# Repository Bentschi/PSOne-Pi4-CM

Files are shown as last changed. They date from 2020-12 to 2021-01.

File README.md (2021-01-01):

## Introduction
The goal of this project is to create open source hardware and software that replaces parts of a PSOne console mainly with a Raspbery PI 4 Compute Module, while remaining the beauty of the console and most of the functionality.
That means you would be able to use your playstation dualshock controllers, the memory card slots, and if i can get it to work the cd drive aswell.

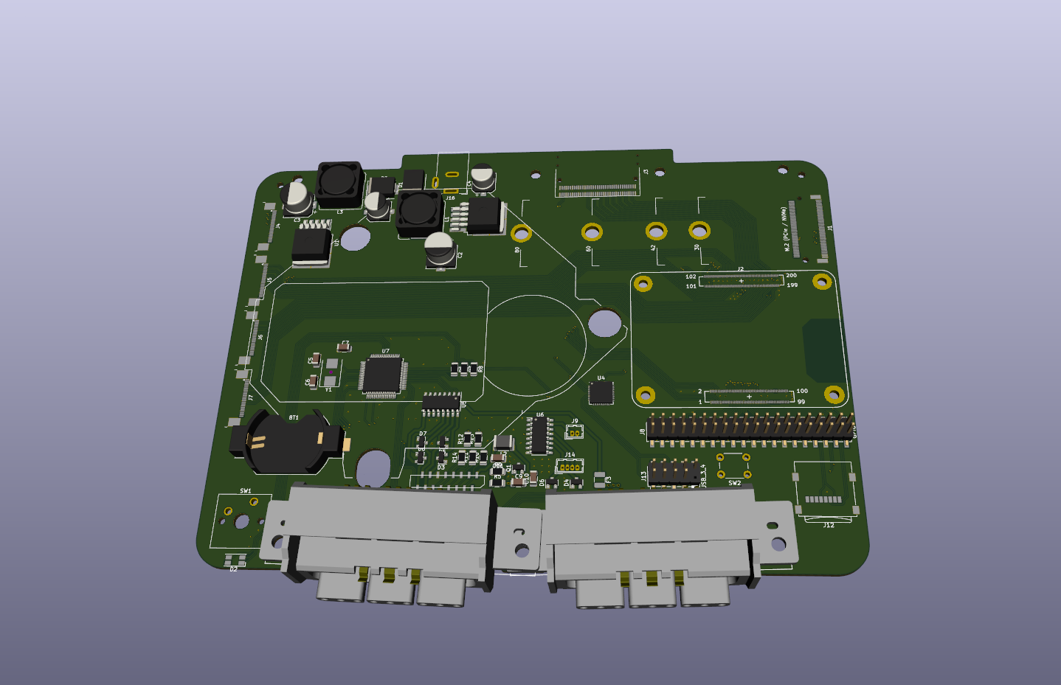
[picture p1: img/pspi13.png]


## Raspberry Pi 4 Compute Module - the heart
As mentioned it will be mainly powered by a Raspberry PI 4 Compute Module, and i will try to break out as much IO as reasonably possible.
Sadly in a PSOne with a CD drive there is not much room to work with, and I decided for a non-destructive method of routing out the ports.
I want to use the connector U10-A074-361T from Amphenol (also known as Slim SAS, and used mostly in servers).
The connector is not really cheap and a little wider than the AV multi out.
But that is the price to pay to not destroy the case of the console, and if the connector is inset in the existing hole it will fit.
With that connector I will route dual HDMI, the gigabit network interface and USB 2.0 out of the back.
As a power port I will use a USB type C receptacle.
A cable that connects to that connector could look something like the following picture.

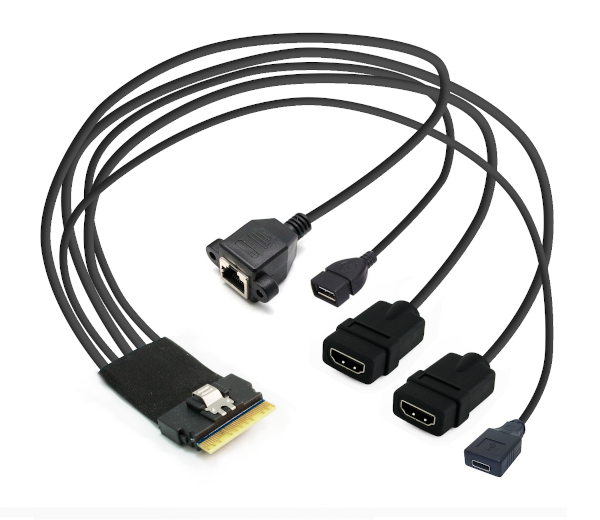
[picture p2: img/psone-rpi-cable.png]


Alternatively a hub could be designed with said ports and maybe a few extras like usb hub and sound.

I will also add the barrel plug you find on a PSOne.
To save some cost and precious board space the Dual Shock function will most certainly only be enabled by using this barrel plug.
The original PSOne power supply (7.5V / 2.2A) seems to be enough to power this entire system (estimated-power-consumption.ods), however when using a M.2 SSD I would suggest to use a better power supply like the one for the Playstation 2 slim (8.5V / 5.6A).

The PCIe i want to use for a M.2 card interface. and i would love to split the pcie lane for USB 3.0 aswell, but then again i want to stay in a reasonable price range for the parts.
The M.2 slot will be able to hold up to 22x60mm cards, and for 22x80mm cards there would be about 7mm vertical clearance, since the only place where a M.2 slot would make sense interferes a little bit with the cd drive.
Sadly I needed more room for the internal power supply, so I had to remove the footprint (mounting hole) for 22x110mm cards.

I haven't managed to find a good place for a SD card holder, but i will route out the traces at least and put a footprint somewhere internally.
I will route out the DSI and CSI connectors aswell, even if i don't really see a use inside a console for them.

There will be an internal 4 port USB 2.0 hub from the PIs USB 2.0 interface.
One of these 4 USB lines will be routed through the Slim SAS connector.
2 of these USB 2.0 lines will be broken out to an internal 9-Pin USB Header, like you find on motherboards.
And the last USB 2.0 will be used to connect to a STM32F103 chip, that will interface the PSOne peripherals.

## STM32F103 - the PSOne interface
The intended use of the STM32F103 chip is to read from and write to the PSOne controller ports and memory card slots, and hopefully if i can get it to work the cd drive aswell.

The STM32F103 chip will communicate with the Raspberry PI Compute Module via USB 2.0 and will introduce itself as a compound device.
That means that only one USB line is required, and the STM32F103 will be recognized as multiple devices which would be 2x game controllers, 2x mass storage devices (the memory card slots), a cd drive, and probably a device that controls the PWMs for the power LED (RGB of course) and fan in the console.

I want to use a USB type C receptacle to power the console, and i have the idea that if the console is turned off or the Compute Module is not populated, and the console is plugged into a USB Host device (like a Computer), that the USB from the STM32F103 shall be passed through this USB type C connector, so that it is possible to use the PSOne peripherals on other devices aswell.

I am aware that CD drives are obsolete by todays standards, and that it is not gonna be that easy to interface the cd assembly, since there is no documentation about it or a standard like IDE or SATA used.
But for completeness i would want to have it working. And if i get it working it would be pretty simple to make it read actual Playstation CDs since the copy protection is not too complicated if you have full control over the entire CD assembly anyway.

## Cooling the Compute Module
Realisticly a flat fan like in laptops should probably be used and a shroud should be designed, that the air is taken from above the M.2 slot and pushed over the compute module, and with the shroud then directed to the bottom right vent holes on the console.
A connector for a fan (5V / 1A max), PWM controlled by the STM32 will be available, sharing one of the ULN2003 chips that are mainly used for the CD drive.

## Current status
I am currently working on the design and schematic for the board in KiCad.
I want to get as much done as possible until i order a PCB from that to test everything.

I want to mention that I have repaired a lot of older consoles in the past and I have very good knowledge of how these devices actually work.
And with all that knowledge, together with my very good programming skills, and my passion about old consoles and interrest in electronics, i think i have everything i need to get this project working.
But i have to say, even if i am aware of most of the design rules and guidelines, i have never designed a PCB before that i actually ordered to manufacture.
So this would be my very first.

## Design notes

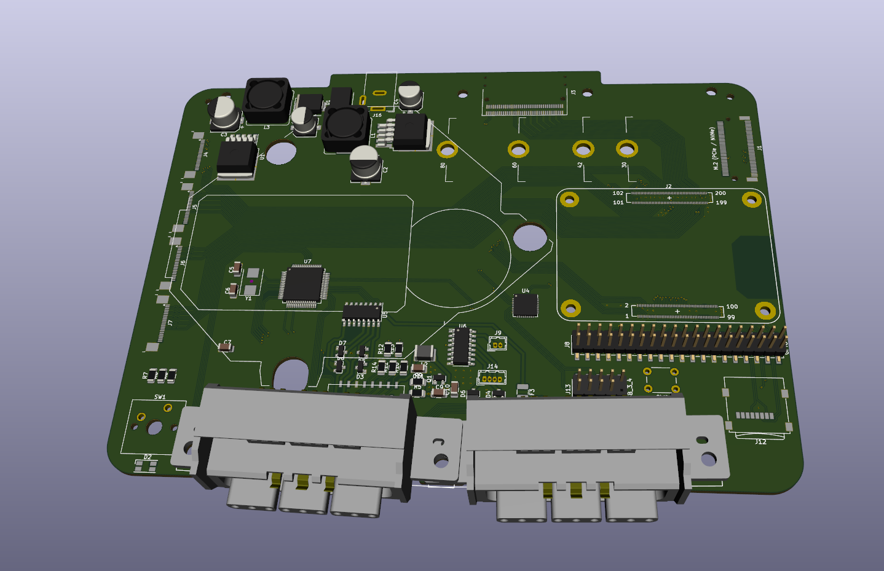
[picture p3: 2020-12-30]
img/pspi12.png

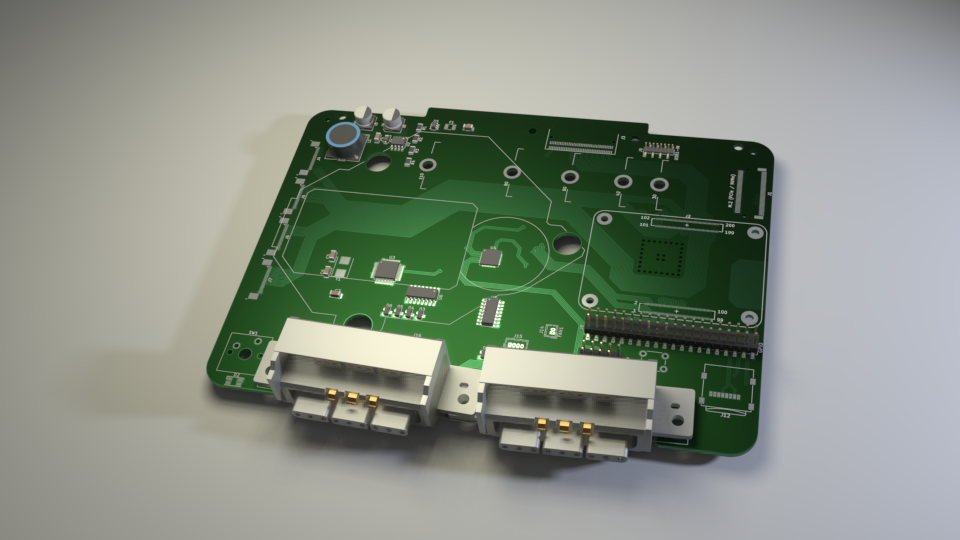
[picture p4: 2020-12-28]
img/pspi11.png

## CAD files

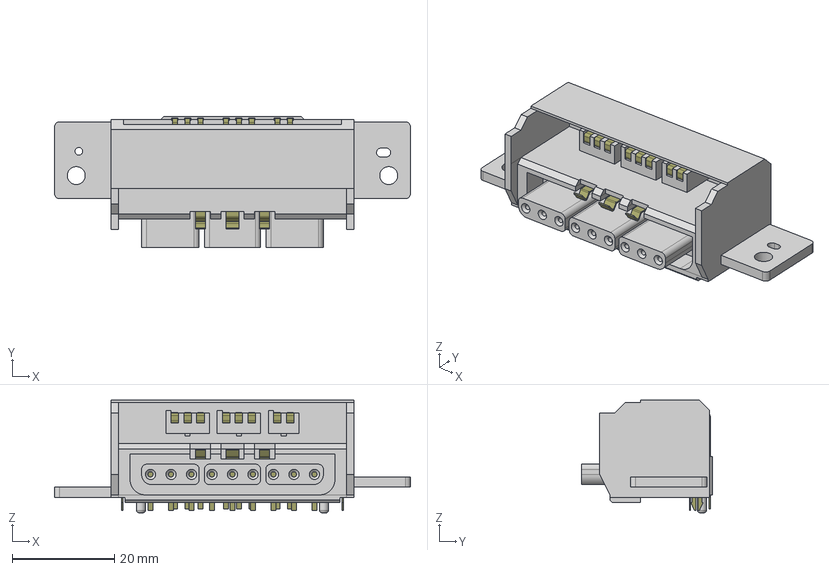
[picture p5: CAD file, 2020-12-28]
freecad/psone-controller-port.step
69.5 x 25.5 x 22.0 mm

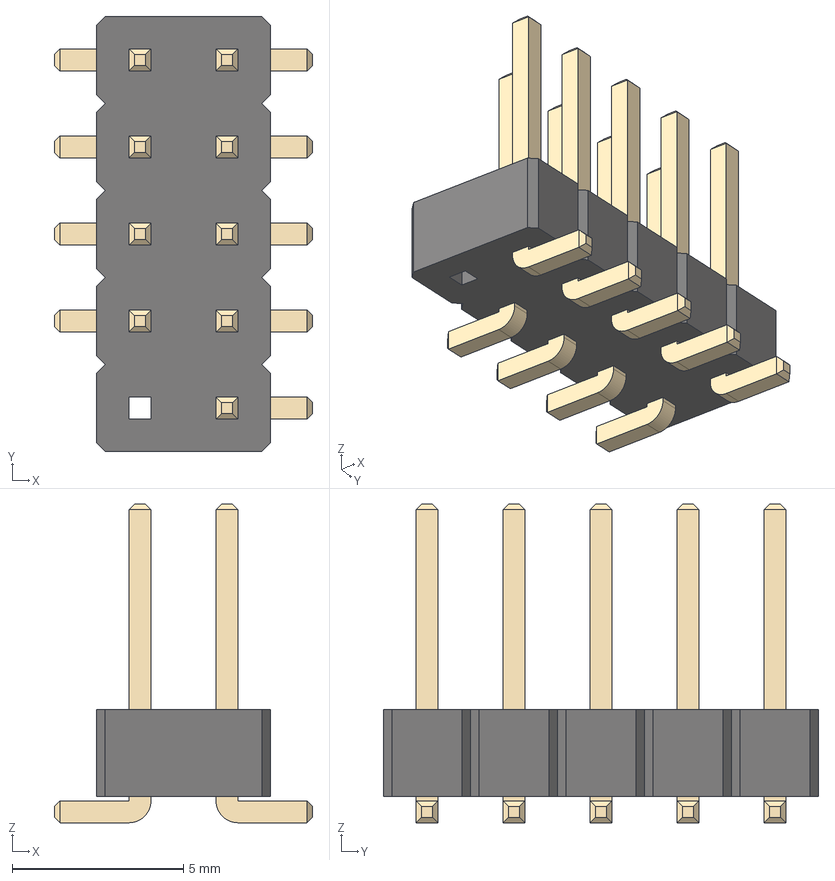
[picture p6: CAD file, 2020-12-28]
freecad/PinHeader_2xUSB2_P2.54mm_Vertical_SMD.step
7.54 x 12.7 x 9.30 mm

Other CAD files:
freecad/psone-controller-port3.FCStd
freecad/PinHeader_2xUSB2_P2.54mm_Vertical_SMD.FCStd

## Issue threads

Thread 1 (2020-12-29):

Need advice for the power supply

Bentschi, 2020-12-29:
Hello,
So here is the scenario:
I want for power inputs a barrel plug with something around the +7.5V like the original PSOne used and alternatively i want to power everything with USB C +5V.

I need obviously +5V for the compute module, HDMI, USB, GPIO and the CD drive (motors)
I need +3.3V for the STM32, the M.2 card interface, the internal USB hub, GPIO, PSOne peripherals and the CD drive (focus and tracking coils and logic)
And I need +7.5V for the rumble motors in Playstation dual shock controllers.

I could consider to take the power for the rumble motors straight from the barrel plug or alternatively +5V and then its just not that powerful.
But i am thinking about taking the voltage from either USB C +5V or from the barrel plug, and convert that with a buck-boost converter to +7.5V.
And use a buck convertor for +5V from that +7.5V.
For +3.3V the 600mA the Compute Module provides would probably be enough, but from what i gather from the datasheet (https://datasheets.raspberrypi.org/cm4/cm4-datasheet.pdf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) the +3.3V output will not be available when the compute module is in low power state.
So i will have to make my own +3.3V circuit for the STM32 that should power down and wake the compute module with the consoles power button.
Therefore I'm thinking about something like a circuit using AMS1117.

Here is what I'm thinking about powering up and down the console:
I want to let the the STM32 pull GLOBAL_EN on the compute module low and sleep if the console is not powered up.
Once the power button is pressed the STM32 should wake up (interrupt) and use RUN_PG as input to know the power state of the compute module.
The compute module should then connect to the STM32 via USB once powered up.
If the power button is pressed when everything is powered up, the STM32 will send a shutdown signal to the compute module (as USB keyboard maybe?) and wait until RUN_PG goes low.
Once RUN_PG goes low, the STM32 should also pull GLOBAL_EN low to prevent powering up the compute module again.
After that the STM32 should go back to sleep.

Is this the right way to do it? Or can I improve something about this?

Bentschi, 2021-01-01:
I did some more research and decided to go with +5V and +3.3V step down converters.
And enable the Dual Shock rumble only with the barrel plug (7.5 - 9V).
Putting all estimated power requirements together in a spread sheet, helped me understanding how the internal power supply should be designed.
In my current design the parts are chosen to be efficient and withstand way more than there should be required, so there is room for modifications.
I still need to design power switches that allow to use a +5V input over the USB type C, and some switches like for M.2 to shut them off when they are not needed, but i think i can get that done without help.

Closed 2021-01-01.

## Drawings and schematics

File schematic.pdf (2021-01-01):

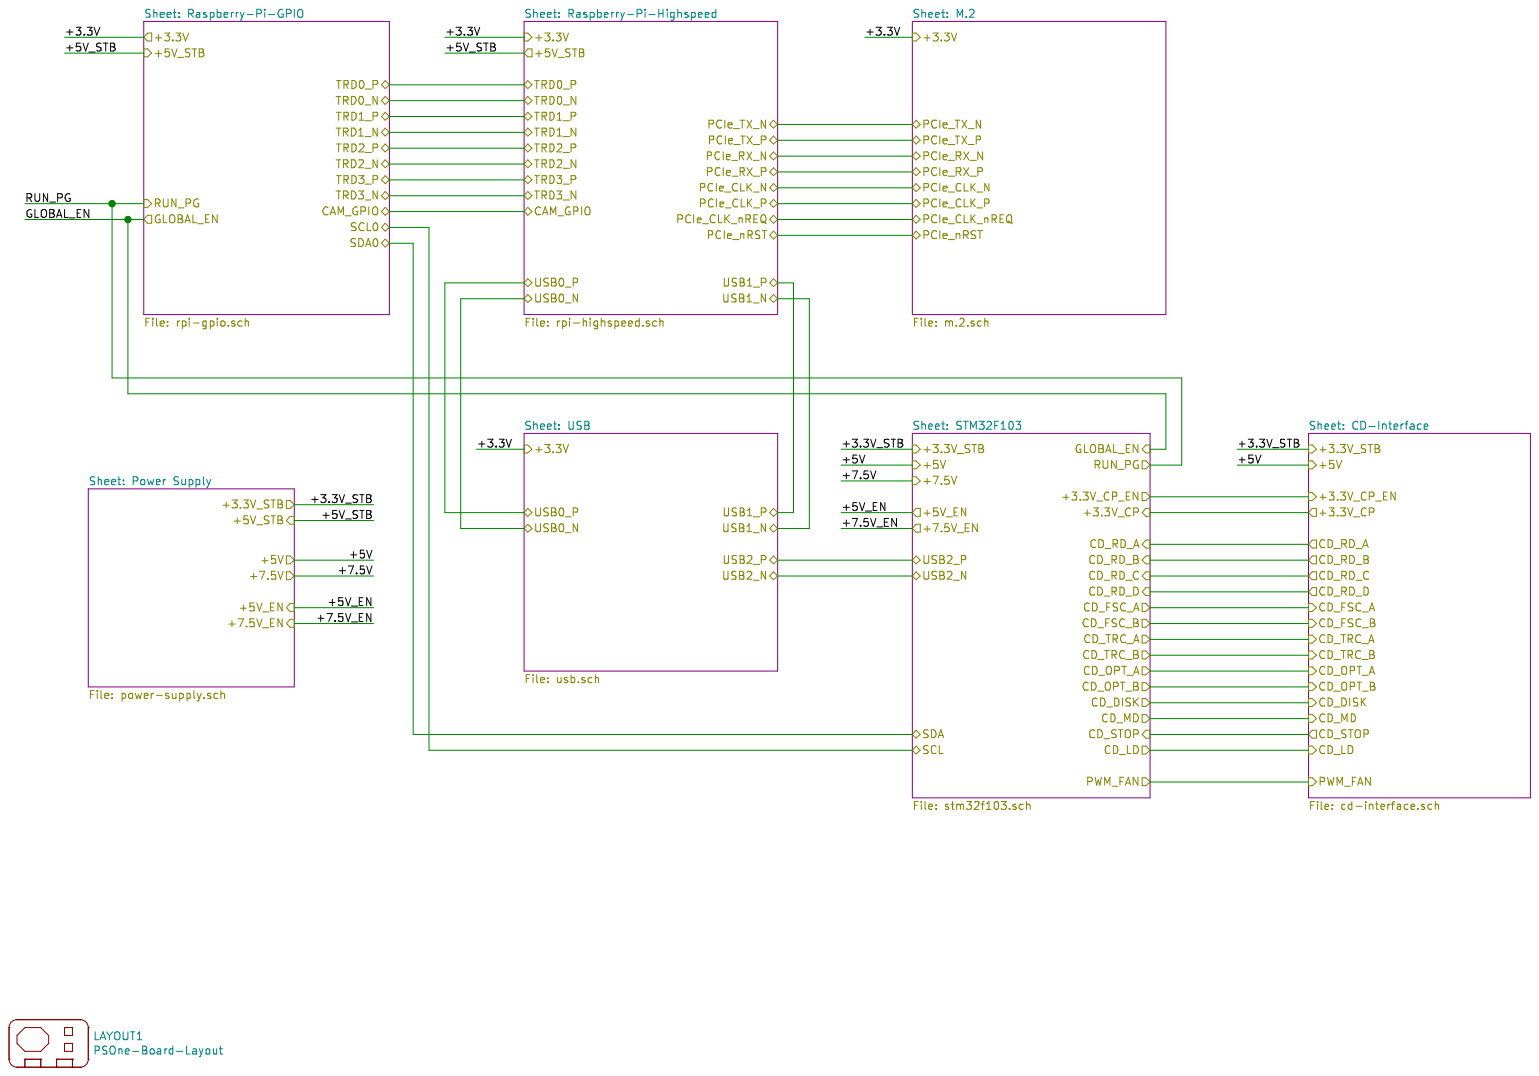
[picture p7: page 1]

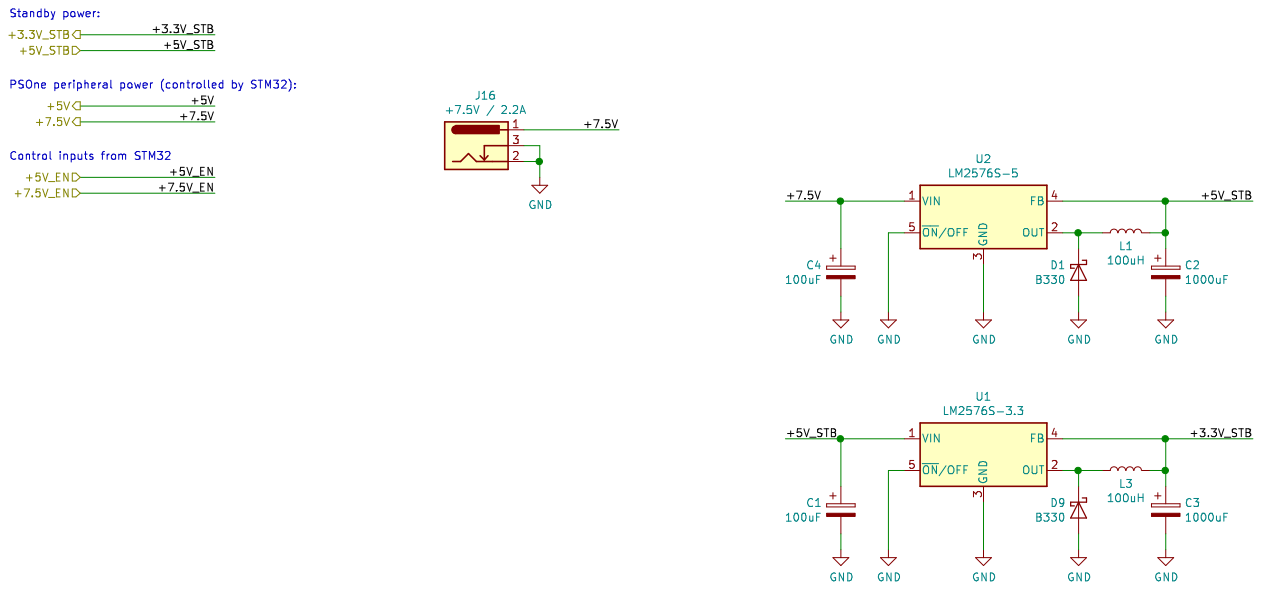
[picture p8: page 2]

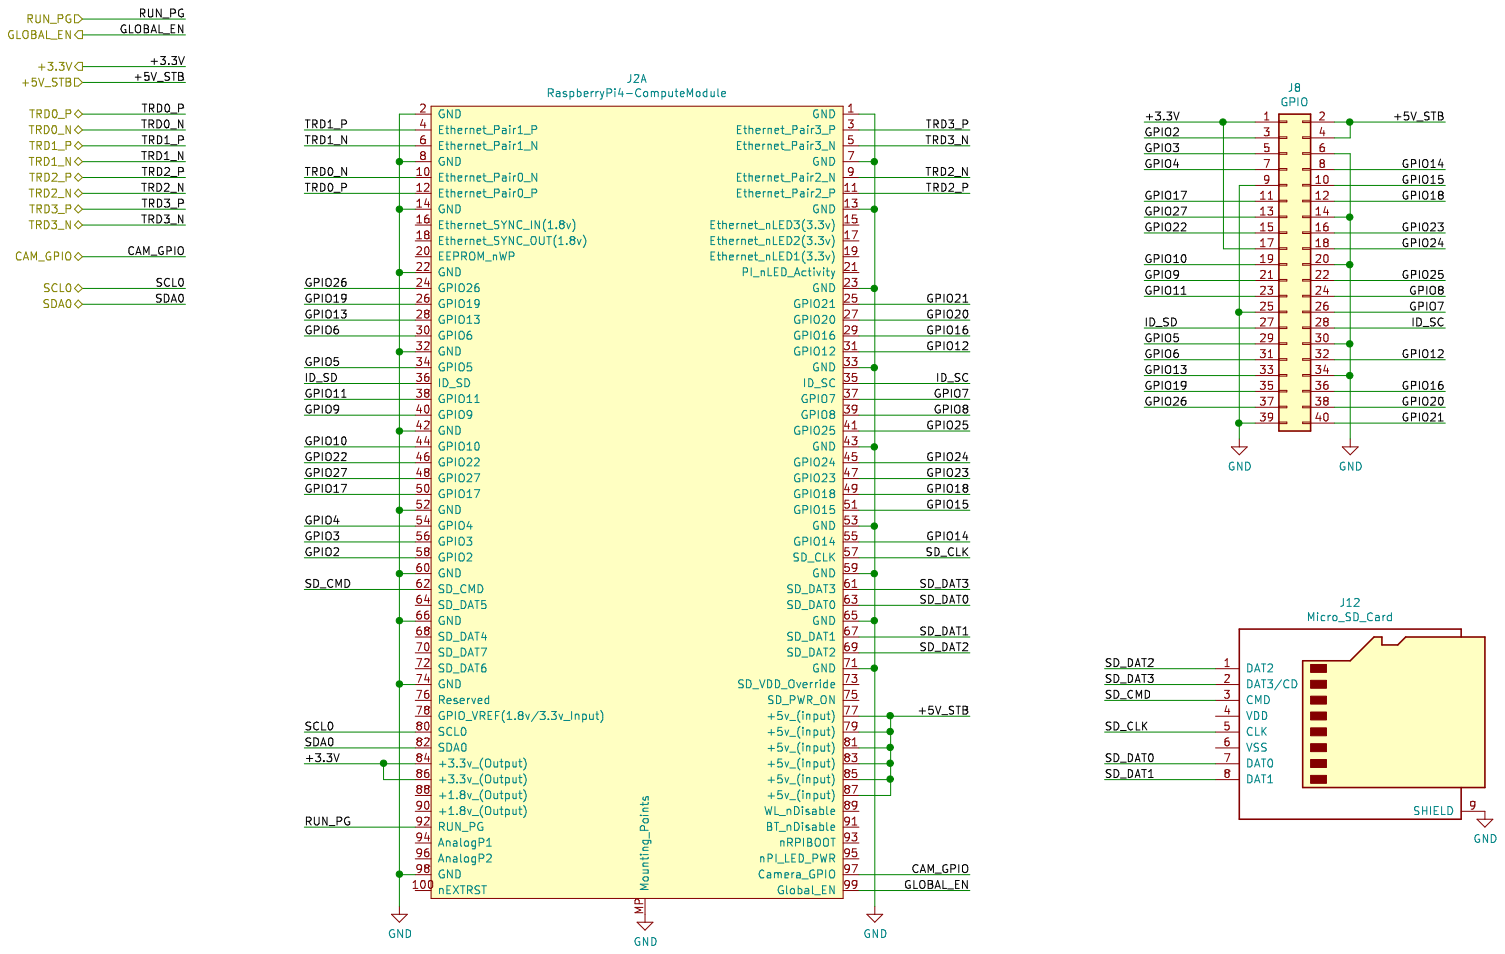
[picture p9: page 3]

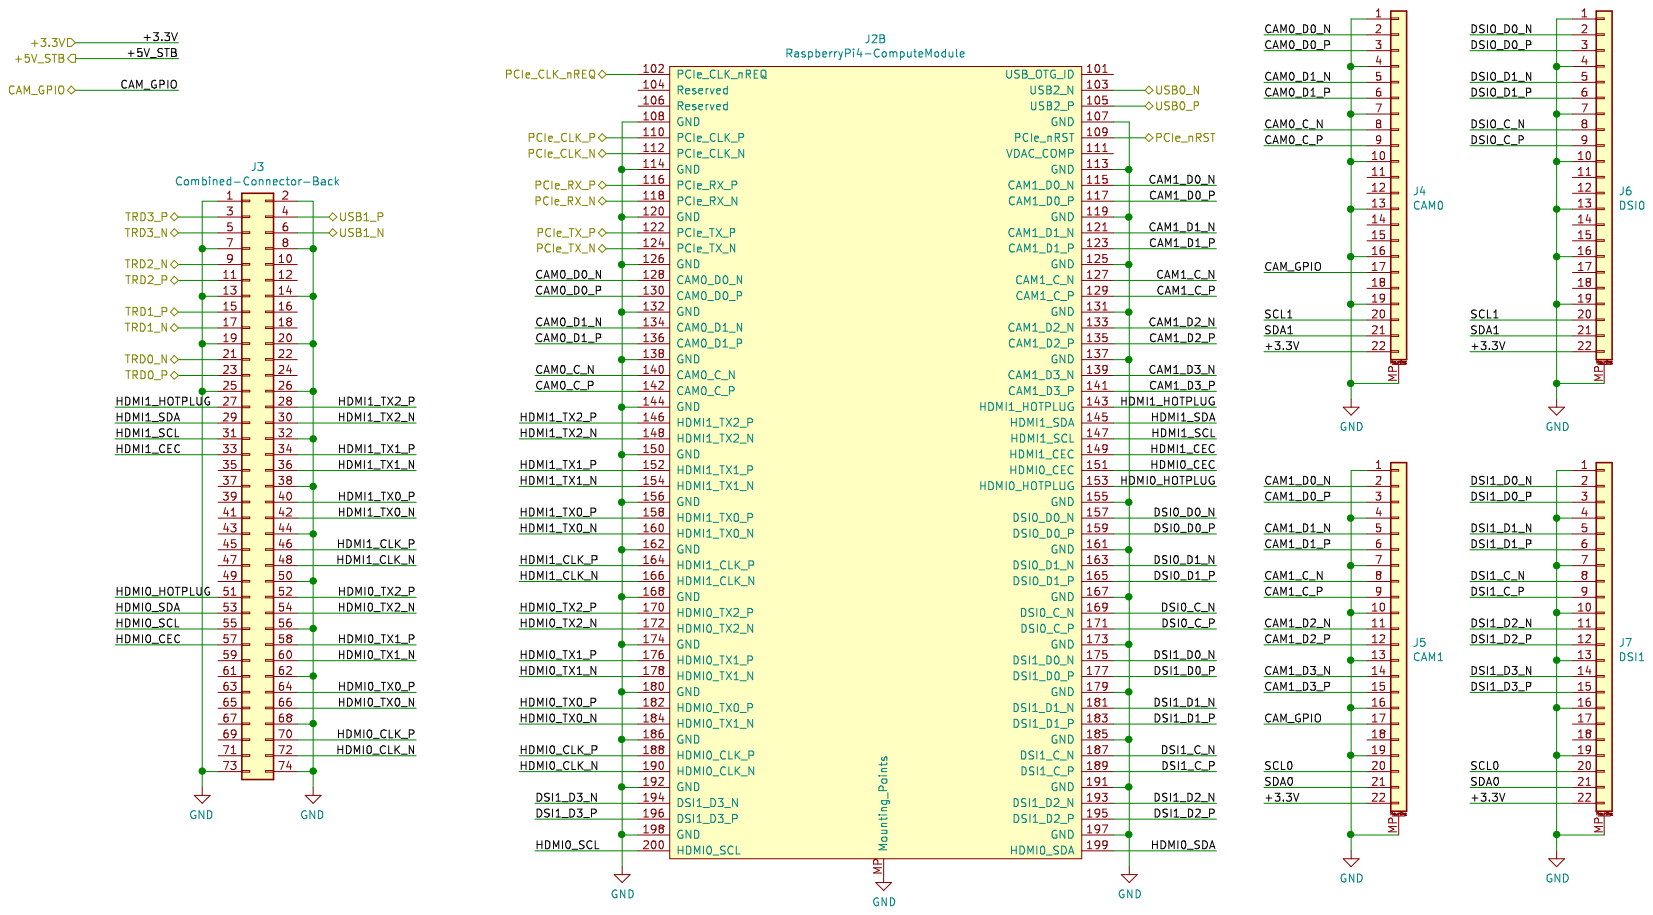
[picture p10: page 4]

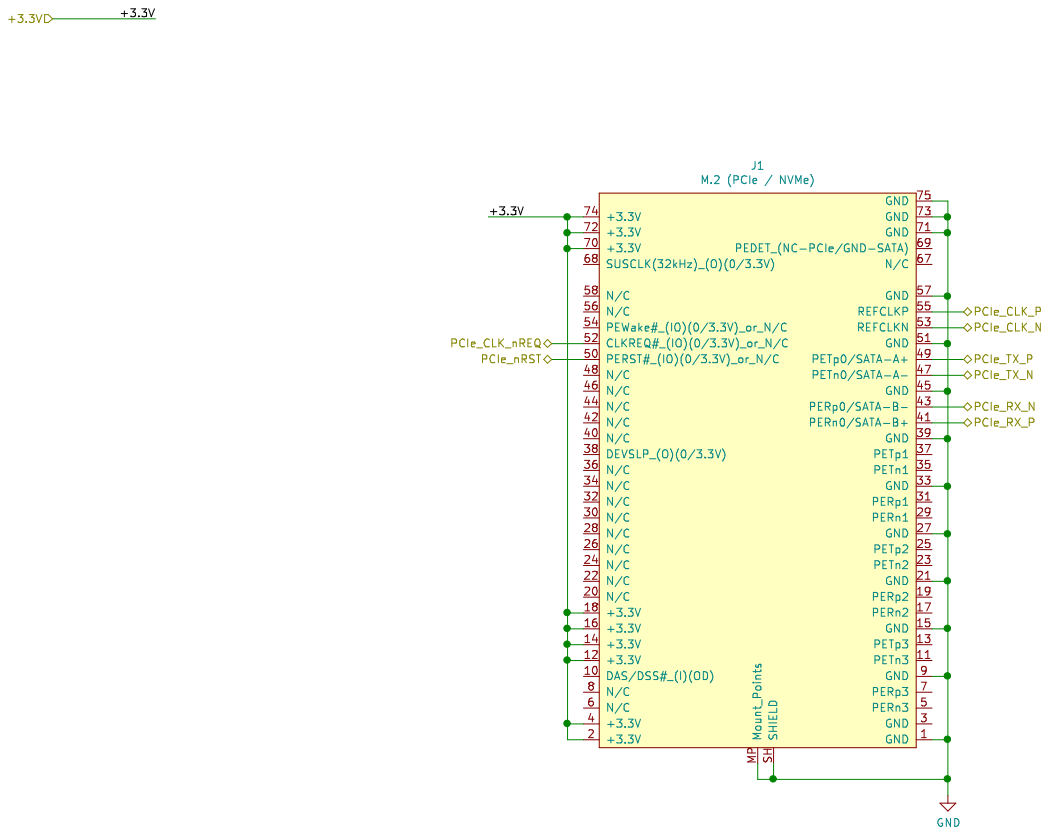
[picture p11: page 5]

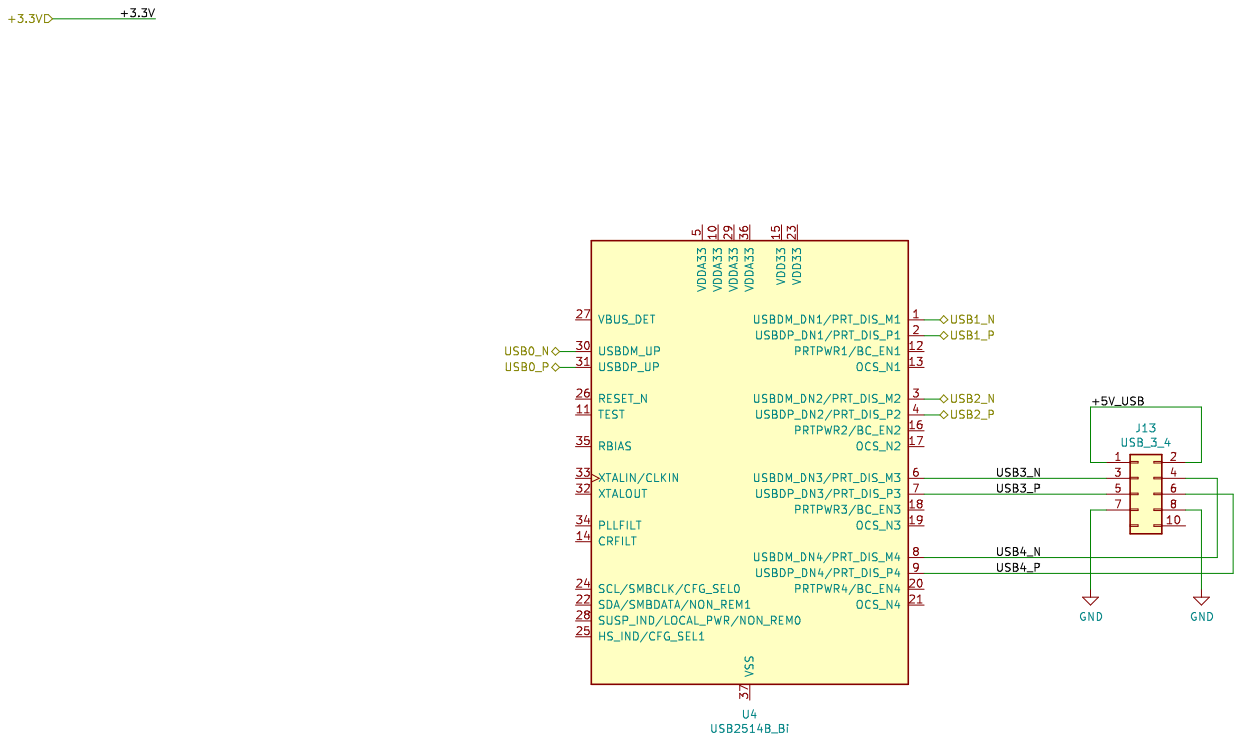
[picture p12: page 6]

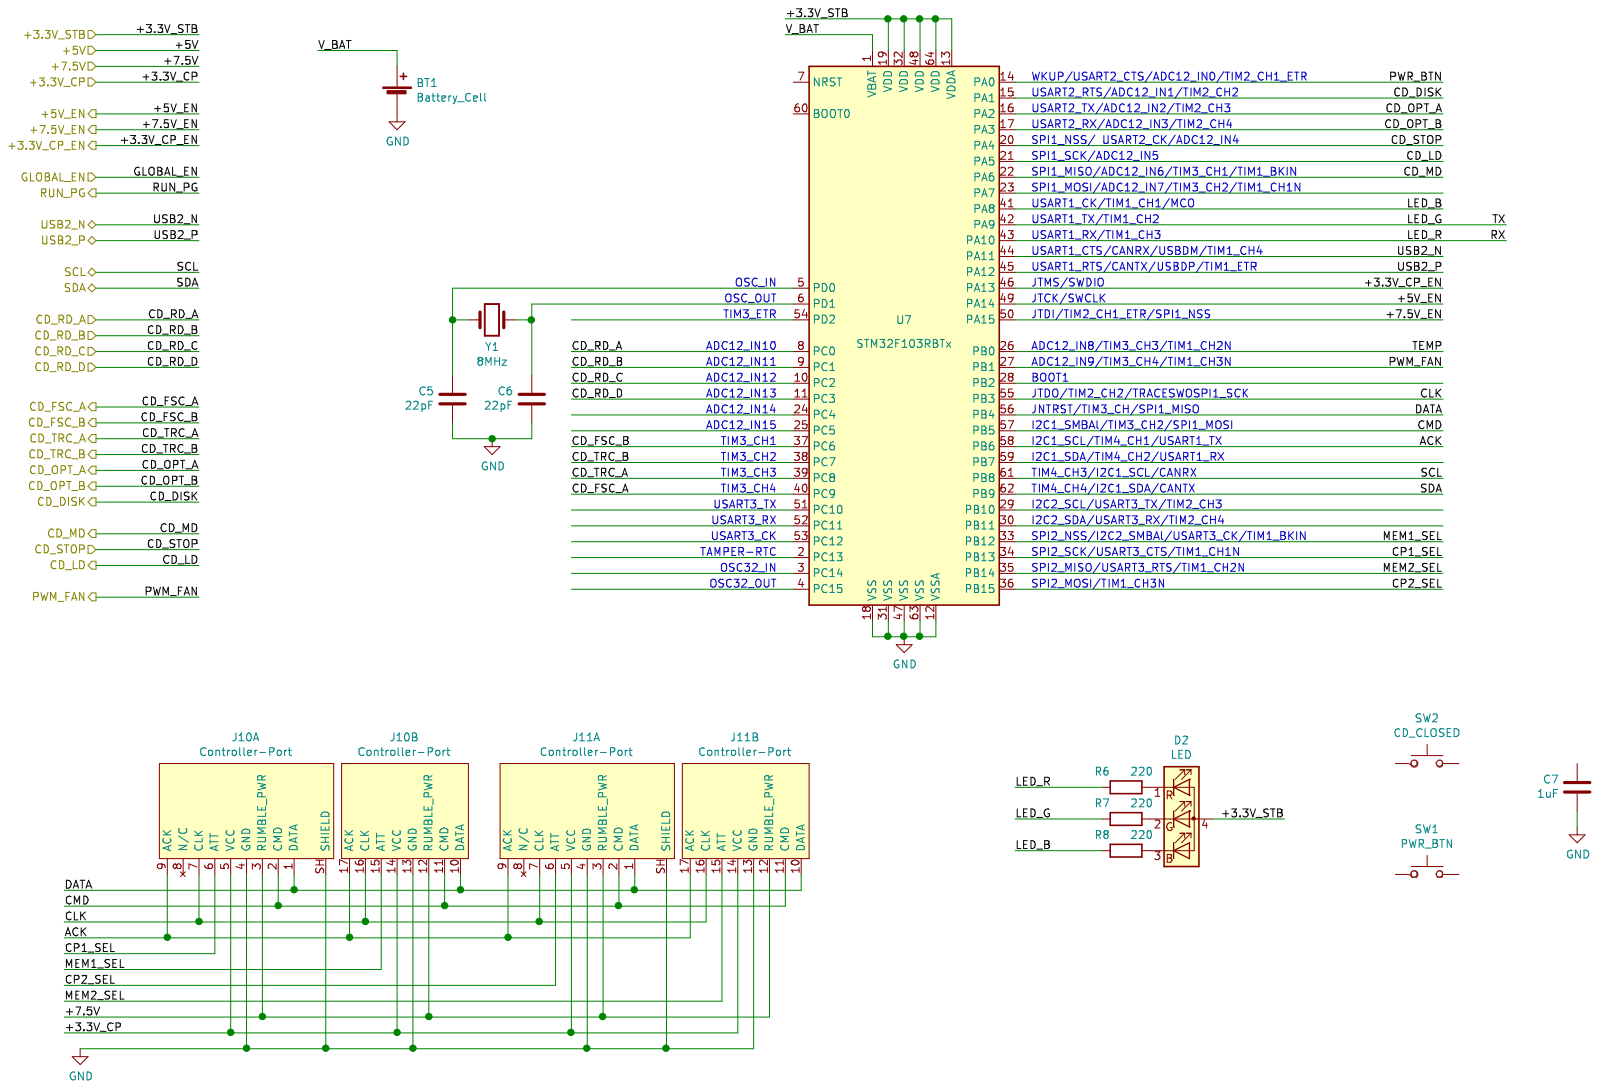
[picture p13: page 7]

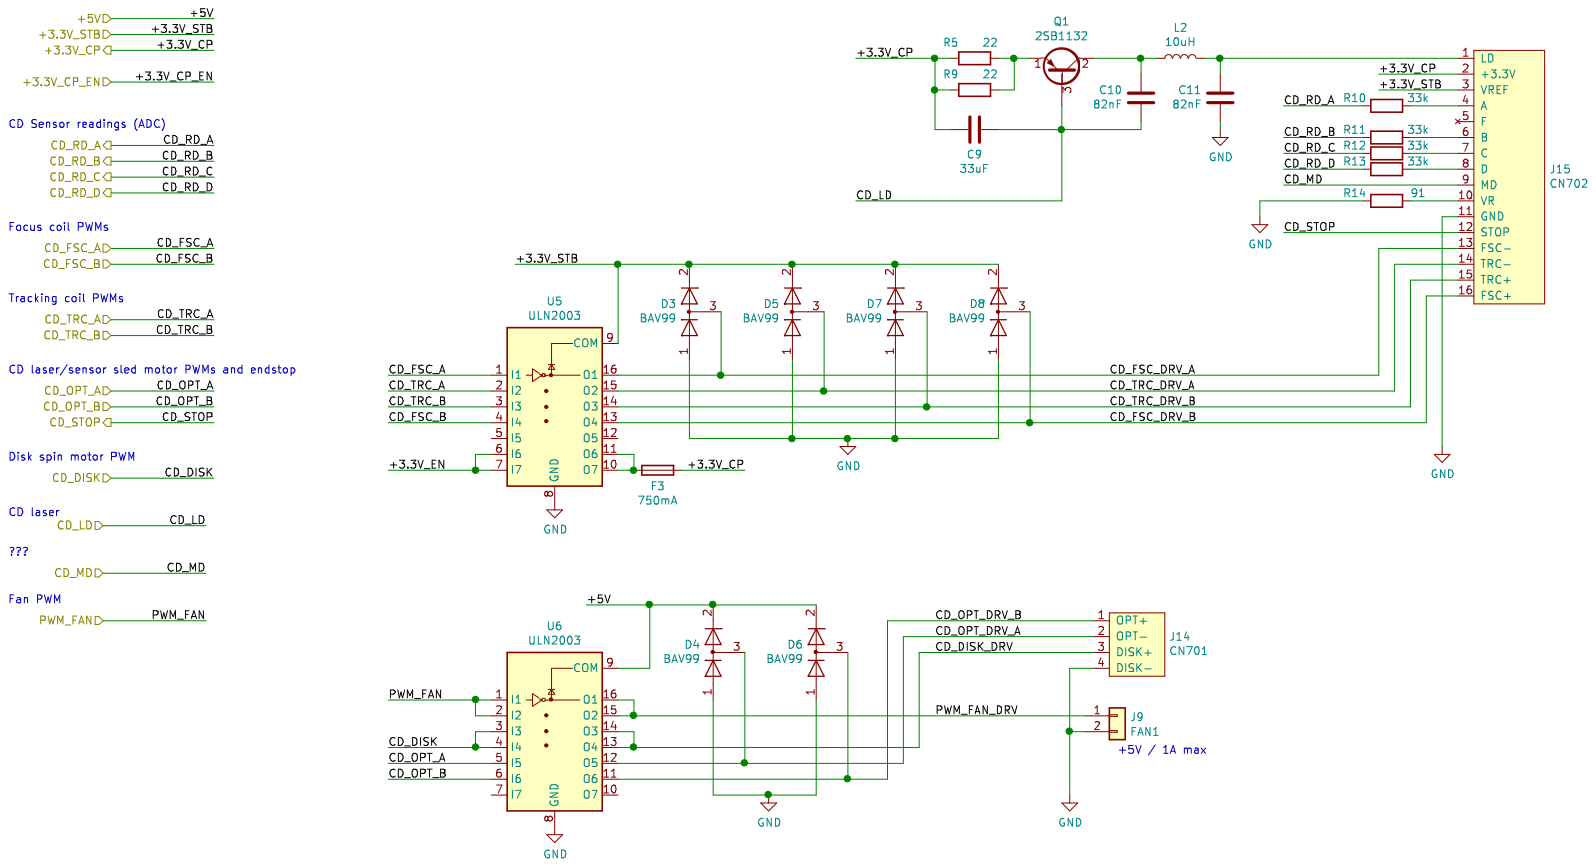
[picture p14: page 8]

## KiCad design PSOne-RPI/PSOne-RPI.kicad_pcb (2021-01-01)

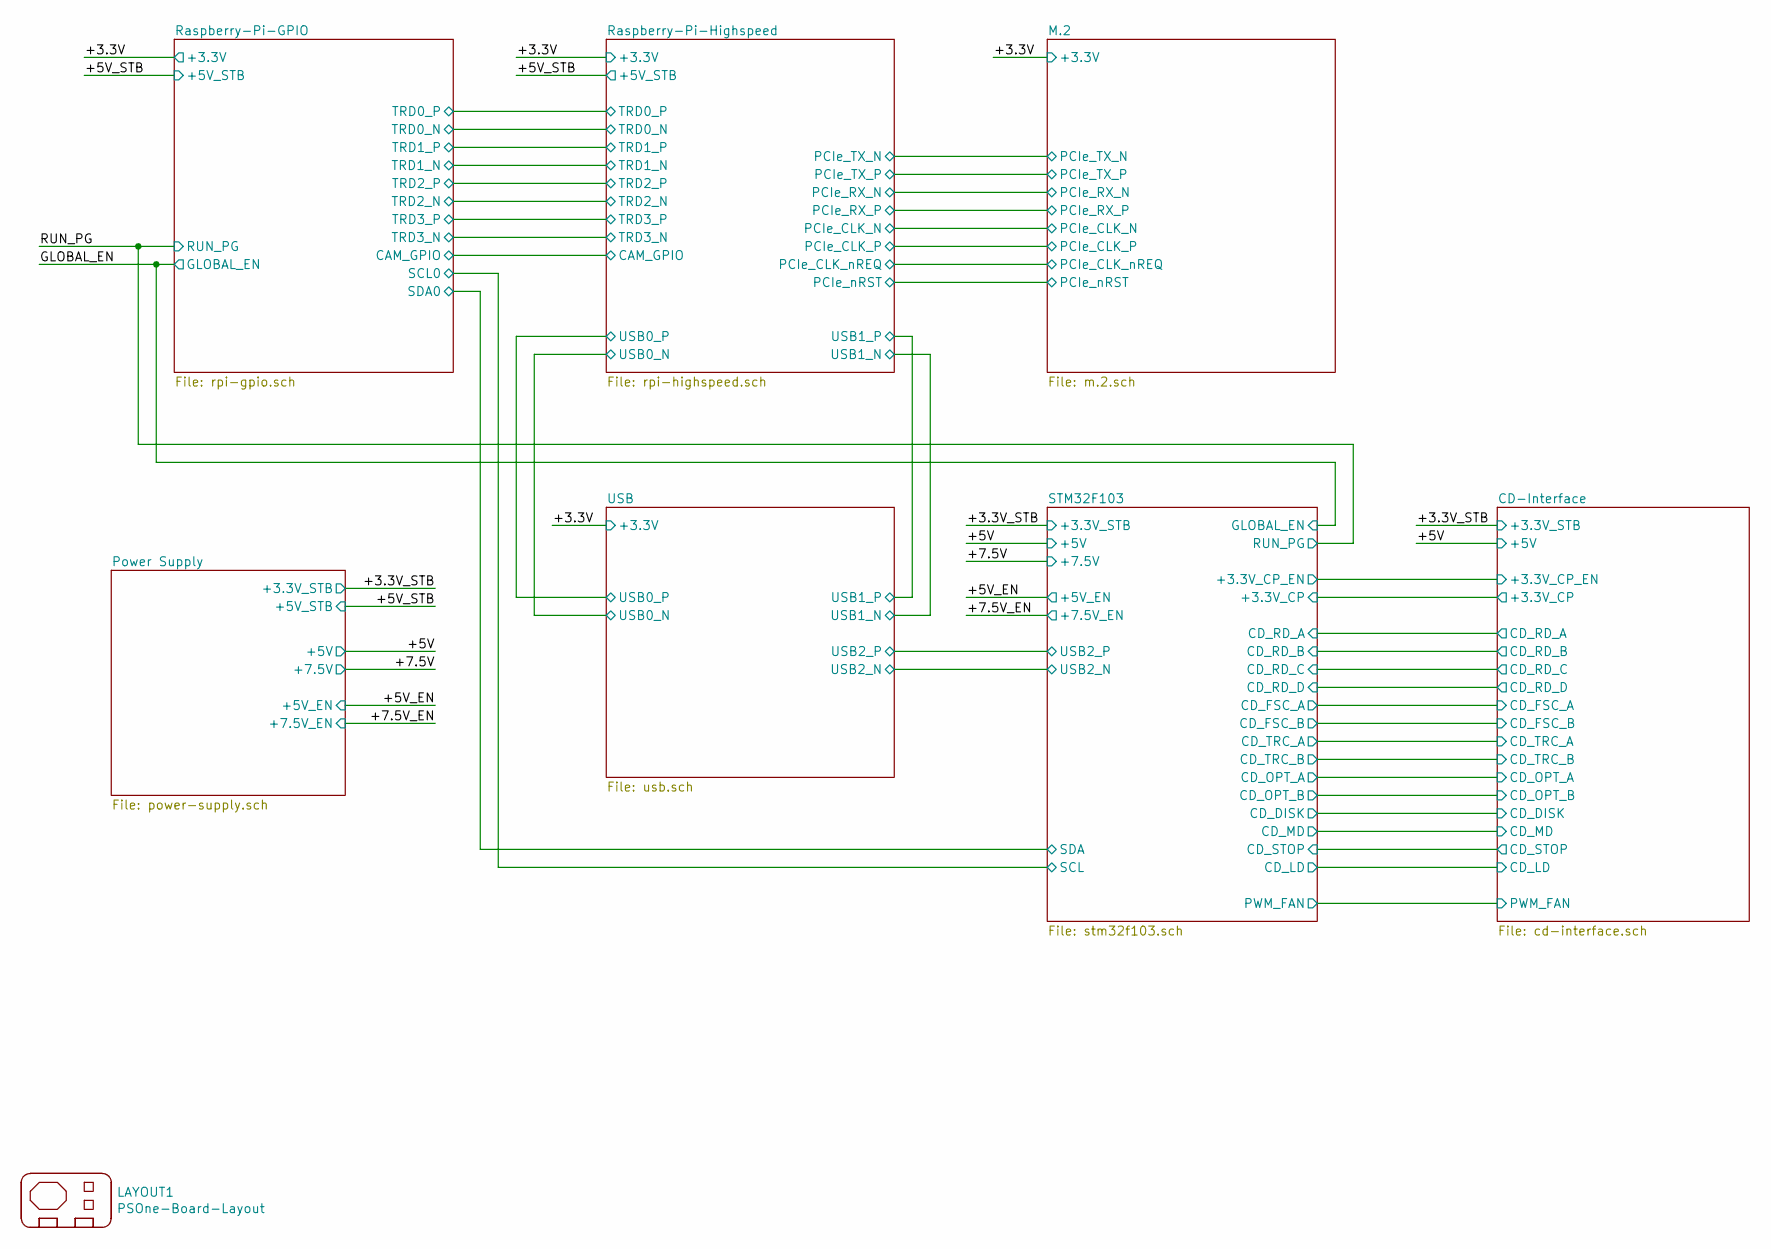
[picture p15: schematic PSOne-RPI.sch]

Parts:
LAYOUT1: PSOne-Board-Layout; PSOne-Layout

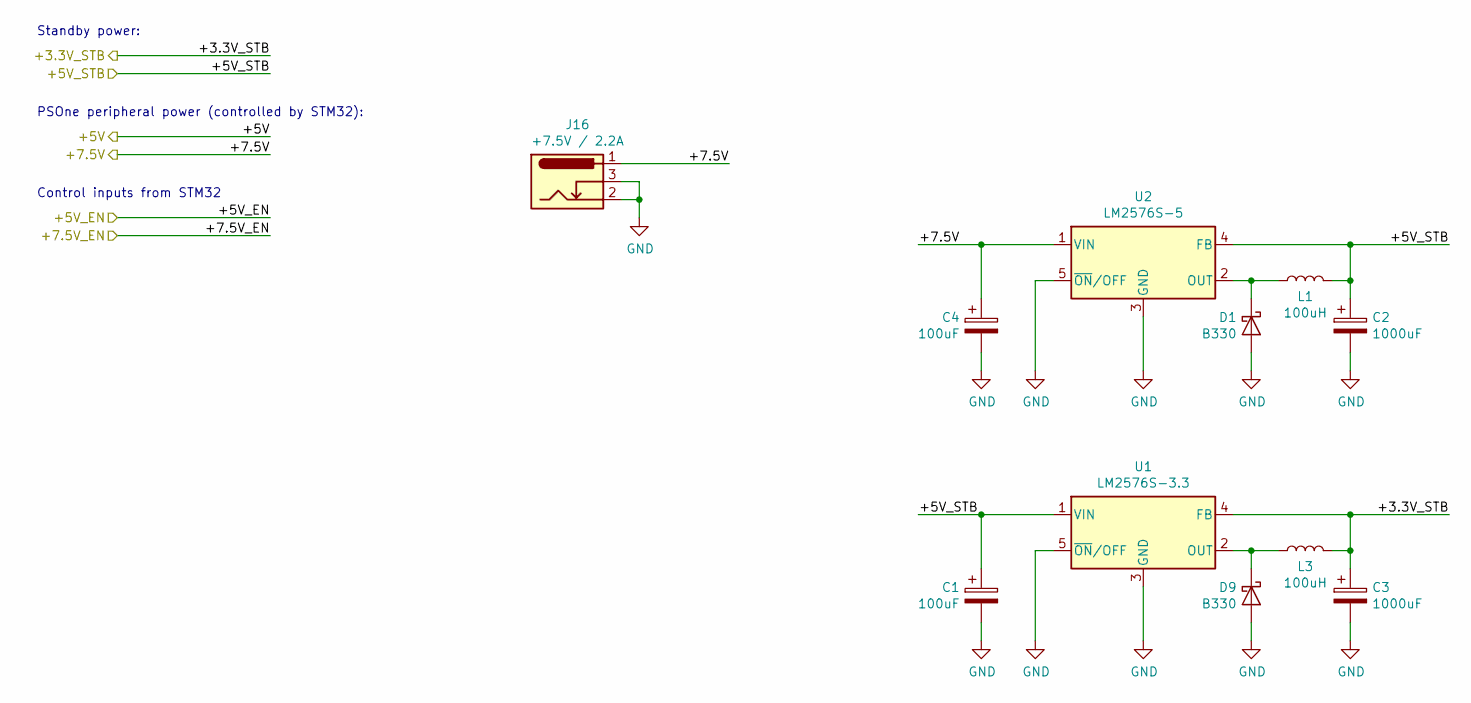
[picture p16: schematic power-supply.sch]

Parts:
C1, C4: 100uF; CP_Elec_6.3x5.8
C2, C3: 1000uF; CP_Elec_8x6.5
D1, D9: B330; D_SMC
J16: +7.5V / 2.2A; BarrelJack_Wuerth_6941xx301002
L1, L3: 100uH; L_Bourns_SRR1260
U1: LM2576S-3.3; TO-263-5_TabPin3
U2: LM2576S-5; TO-263-5_TabPin3

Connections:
/+3.3V_STB: C3.1, L3.2, U1.4 (FB); also elsewhere on the board
/+5V_STB: C1.1, C2.1, L1.2, U1.1 (VIN), U2.4 (FB); also elsewhere on the board
/+7.5V: C4.1, J16.1, U2.1 (VIN); also elsewhere on the board
GND: C1.2, C2.2, C3.2, C4.2, D1.2 (A), D9.2 (A), J16.2, J16.3, U1.3 (GND), U1.5 (~ON~/OFF), U2.3 (GND), U2.5 (~ON~/OFF); also elsewhere on the board
unnamed: D1.1 (K), L1.1, U2.2 (OUT)
unnamed: D9.1 (K), L3.1, U1.2 (OUT)

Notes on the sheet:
Standby power:
PSOne peripheral power (controlled by STM32):
Control inputs from STM32

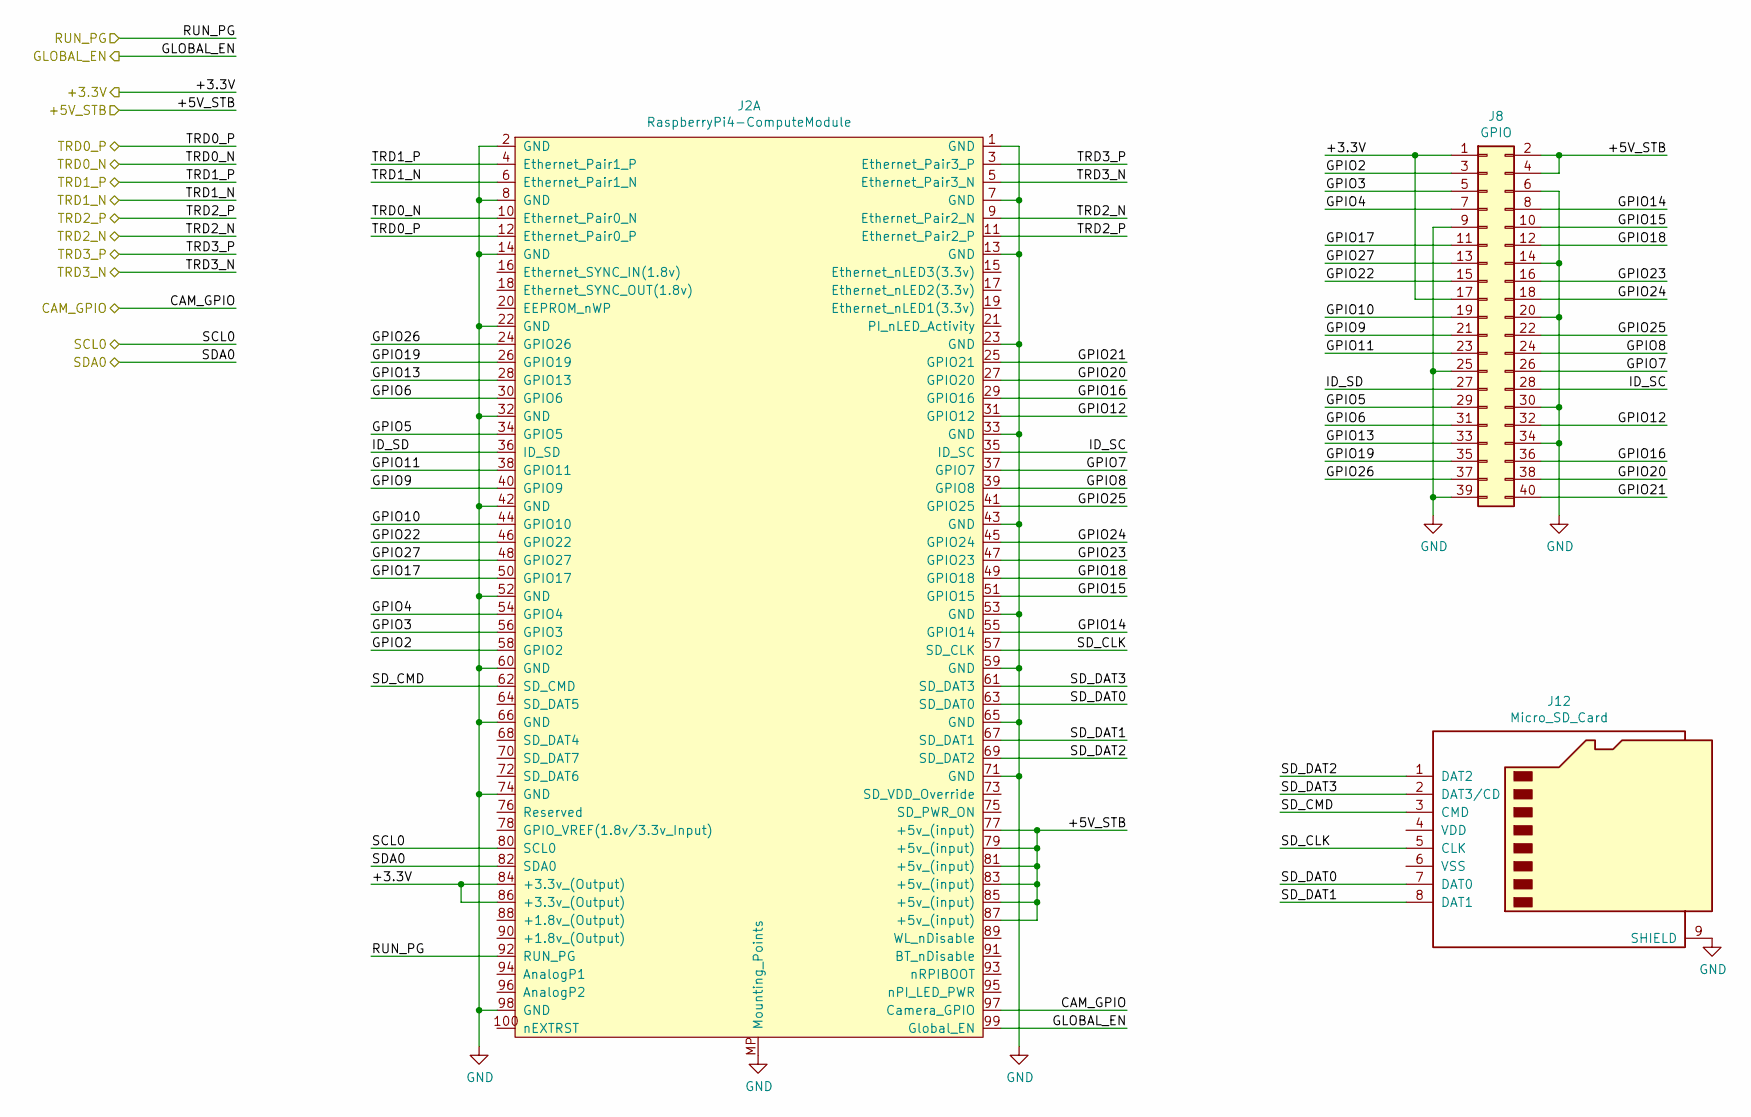
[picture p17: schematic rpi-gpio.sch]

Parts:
J2: RaspberryPi4-ComputeModule
J8: GPIO; PinHeader_2x20_P2.54mm_Vertical_SMD
J12: Micro_SD_Card; microSD_HC_Wuerth_693072010801

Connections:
/+3.3V: J2.84 (+3.3v_(Output)), J2.86 (+3.3v_(Output)), J8.1, J8.17; also elsewhere on the board
/+5V_STB: J2.77 (+5v_(input)), J2.79 (+5v_(input)), J2.81 (+5v_(input)), J2.83 (+5v_(input)), J2.85 (+5v_(input)), J2.87 (+5v_(input)), J8.2, J8.4; also elsewhere on the board
/GLOBAL_EN: J2.99 (Global_EN)
/RUN_PG: J2.92 (RUN_PG)
/Raspberry-Pi-GPIO/CAM_GPIO: J2.97 (Camera_GPIO); also elsewhere on the board
/Raspberry-Pi-GPIO/GPIO2: J2.58 (GPIO2), J8.3
/Raspberry-Pi-GPIO/GPIO3: J2.56 (GPIO3), J8.5
/Raspberry-Pi-GPIO/GPIO4: J2.54 (GPIO4), J8.7
/Raspberry-Pi-GPIO/GPIO5: J2.34 (GPIO5), J8.29
/Raspberry-Pi-GPIO/GPIO6: J2.30 (GPIO6), J8.31
/Raspberry-Pi-GPIO/GPIO7: J2.37 (GPIO7), J8.26
/Raspberry-Pi-GPIO/GPIO8: J2.39 (GPIO8), J8.24
/Raspberry-Pi-GPIO/GPIO9: J2.40 (GPIO9), J8.21
/Raspberry-Pi-GPIO/GPIO10: J2.44 (GPIO10), J8.19
/Raspberry-Pi-GPIO/GPIO11: J2.38 (GPIO11), J8.23
/Raspberry-Pi-GPIO/GPIO12: J2.31 (GPIO12), J8.32
/Raspberry-Pi-GPIO/GPIO13: J2.28 (GPIO13), J8.33
/Raspberry-Pi-GPIO/GPIO14: J2.55 (GPIO14), J8.8
/Raspberry-Pi-GPIO/GPIO15: J2.51 (GPIO15), J8.10
/Raspberry-Pi-GPIO/GPIO16: J2.29 (GPIO16), J8.36
/Raspberry-Pi-GPIO/GPIO17: J2.50 (GPIO17), J8.11
/Raspberry-Pi-GPIO/GPIO18: J2.49 (GPIO18), J8.12
/Raspberry-Pi-GPIO/GPIO19: J2.26 (GPIO19), J8.35
/Raspberry-Pi-GPIO/GPIO20: J2.27 (GPIO20), J8.38
/Raspberry-Pi-GPIO/GPIO21: J2.25 (GPIO21), J8.40
/Raspberry-Pi-GPIO/GPIO22: J2.46 (GPIO22), J8.15
/Raspberry-Pi-GPIO/GPIO23: J2.47 (GPIO23), J8.16
/Raspberry-Pi-GPIO/GPIO24: J2.45 (GPIO24), J8.18
/Raspberry-Pi-GPIO/GPIO25: J2.41 (GPIO25), J8.22
/Raspberry-Pi-GPIO/GPIO26: J2.24 (GPIO26), J8.37
/Raspberry-Pi-GPIO/GPIO27: J2.48 (GPIO27), J8.13
/Raspberry-Pi-GPIO/ID_SC: J2.35 (ID_SC), J8.28
/Raspberry-Pi-GPIO/ID_SD: J2.36 (ID_SD), J8.27
/Raspberry-Pi-GPIO/SD_CLK: J2.57 (SD_CLK), J12.5 (CLK)
/Raspberry-Pi-GPIO/SD_CMD: J2.62 (SD_CMD), J12.3 (CMD)
/Raspberry-Pi-GPIO/SD_DAT0: J2.63 (SD_DAT0), J12.7 (DAT0)
/Raspberry-Pi-GPIO/SD_DAT1: J2.67 (SD_DAT1), J12.8 (DAT1)
/Raspberry-Pi-GPIO/SD_DAT2: J2.69 (SD_DAT2), J12.1 (DAT2)
/Raspberry-Pi-GPIO/SD_DAT3: J2.61 (SD_DAT3), J12.2 (DAT3/CD)
/Raspberry-Pi-GPIO/TRD0_N: J2.10 (Ethernet_Pair0_N); also elsewhere on the board
/Raspberry-Pi-GPIO/TRD0_P: J2.12 (Ethernet_Pair0_P); also elsewhere on the board
/Raspberry-Pi-GPIO/TRD1_N: J2.6 (Ethernet_Pair1_N); also elsewhere on the board
/Raspberry-Pi-GPIO/TRD1_P: J2.4 (Ethernet_Pair1_P); also elsewhere on the board
/Raspberry-Pi-GPIO/TRD2_N: J2.9 (Ethernet_Pair2_N); also elsewhere on the board
/Raspberry-Pi-GPIO/TRD2_P: J2.11 (Ethernet_Pair2_P); also elsewhere on the board
/Raspberry-Pi-GPIO/TRD3_N: J2.5 (Ethernet_Pair3_N); also elsewhere on the board
/Raspberry-Pi-GPIO/TRD3_P: J2.3 (Ethernet_Pair3_P); also elsewhere on the board
/STM32F103/SCL: J2.80 (SCL0); also elsewhere on the board
/STM32F103/SDA: J2.82 (SDA0); also elsewhere on the board
GND: J2.1 (GND), J2.2 (GND), J2.7 (GND), J2.8 (GND), J2.13 (GND), J2.14 (GND), J2.22 (GND), J2.23 (GND), J2.32 (GND), J2.33 (GND), J2.42 (GND), J2.43 (GND), J2.52 (GND), J2.53 (GND), J2.59 (GND), J2.60 (GND), J2.65 (GND), J2.66 (GND), J2.71 (GND), J2.74 (GND), J2.98 (GND), J2.MP (Mounting_Points), J8.6, J8.9, J8.14, J8.20, J8.25, J8.30, J8.34, J8.39, J12.9 (SHIELD); also elsewhere on the board

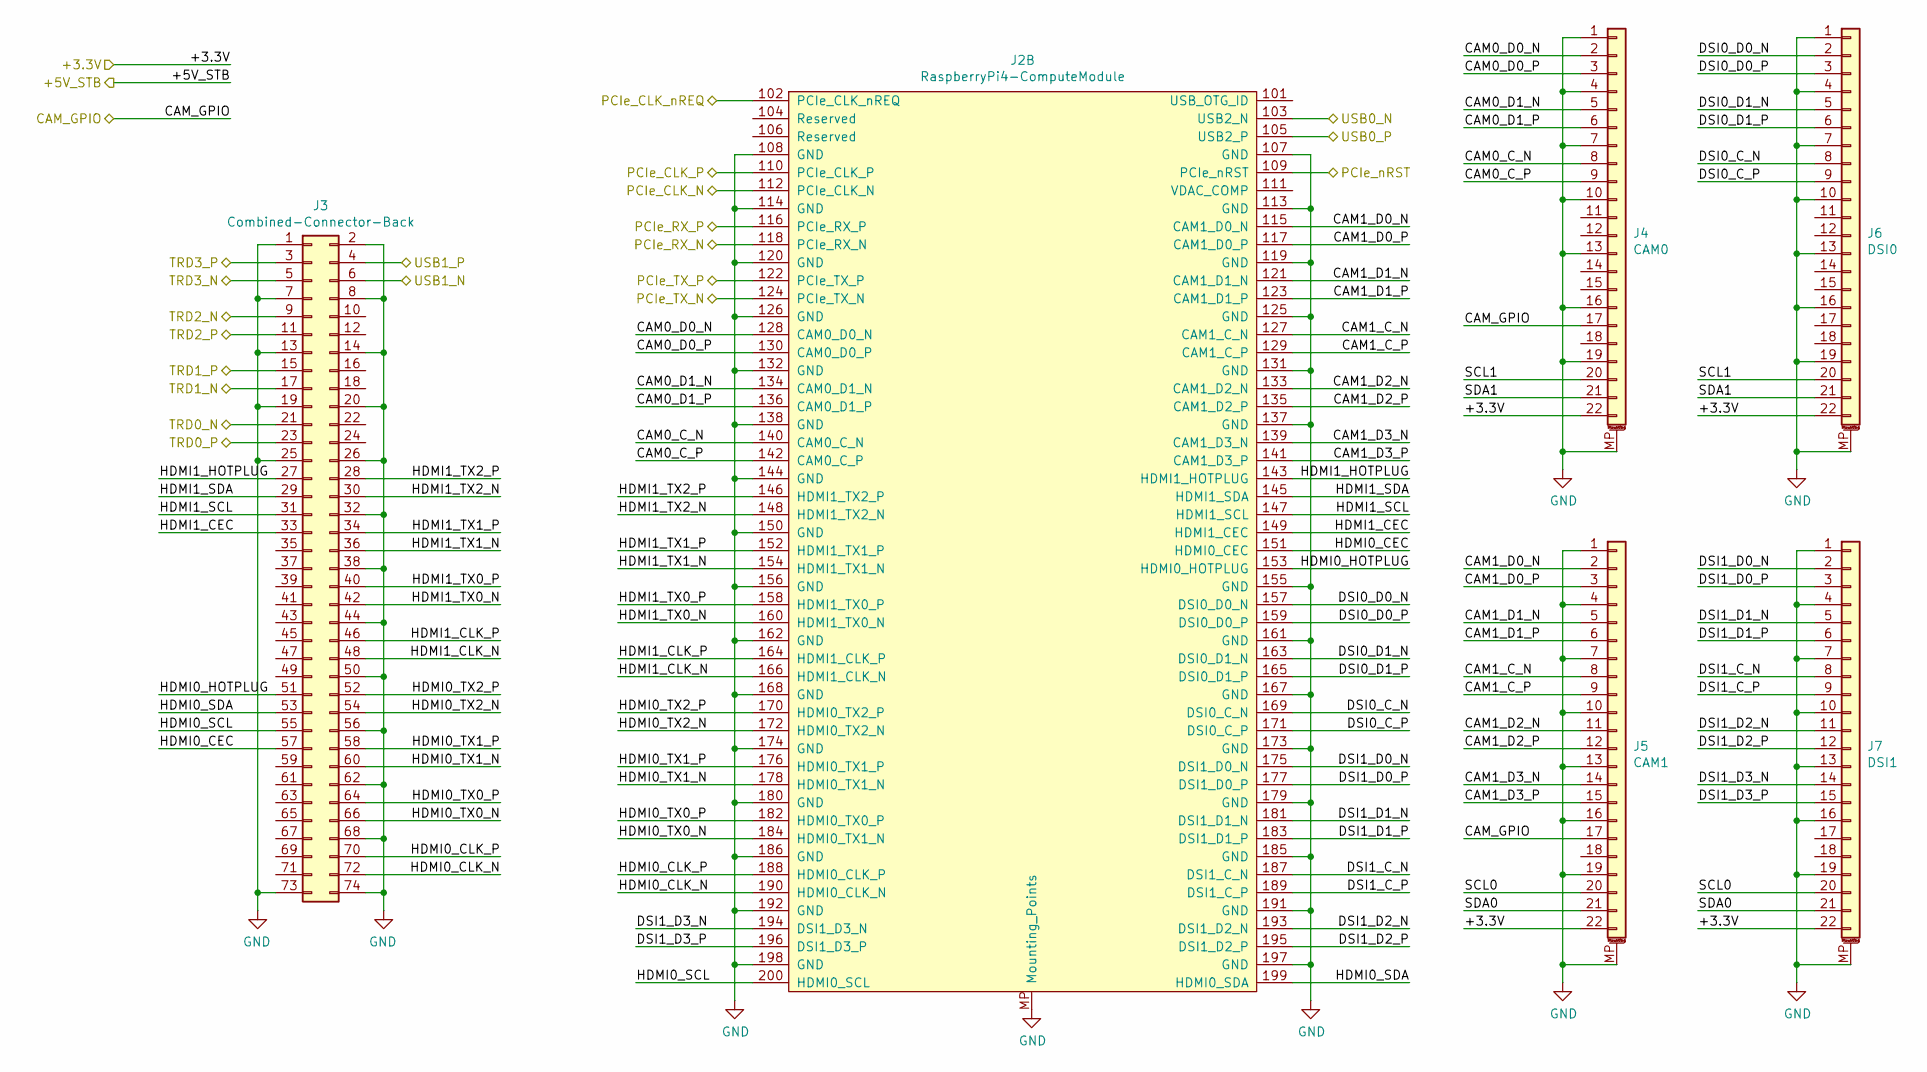
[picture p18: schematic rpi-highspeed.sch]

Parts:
J2: RaspberryPi4-ComputeModule
J3: Combined-Connector-Back; U10-A074-361T
J4: CAM0; TE_2-1734839-2_1x22-1MP_P0.5mm_Horizontal
J5: CAM1; TE_2-1734839-2_1x22-1MP_P0.5mm_Horizontal
J6: DSI0; TE_2-1734839-2_1x22-1MP_P0.5mm_Horizontal
J7: DSI1; TE_2-1734839-2_1x22-1MP_P0.5mm_Horizontal

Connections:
/+3.3V: J4.22, J5.22, J6.22, J7.22; also elsewhere on the board
/M.2/PCIe_CLK_N: J2.112 (PCIe_CLK_N); also elsewhere on the board
/M.2/PCIe_CLK_P: J2.110 (PCIe_CLK_P); also elsewhere on the board
/M.2/PCIe_CLK_nREQ: J2.102 (PCIe_CLK_nREQ); also elsewhere on the board
/M.2/PCIe_RX_N: J2.118 (PCIe_RX_N); also elsewhere on the board
/M.2/PCIe_RX_P: J2.116 (PCIe_RX_P); also elsewhere on the board
/M.2/PCIe_TX_N: J2.124 (PCIe_TX_N); also elsewhere on the board
/M.2/PCIe_TX_P: J2.122 (PCIe_TX_P); also elsewhere on the board
/M.2/PCIe_nRST: J2.109 (PCIe_nRST); also elsewhere on the board
/Raspberry-Pi-GPIO/CAM_GPIO: J4.17, J5.17; also elsewhere on the board
/Raspberry-Pi-GPIO/TRD0_N: J3.21; also elsewhere on the board
/Raspberry-Pi-GPIO/TRD0_P: J3.23; also elsewhere on the board
/Raspberry-Pi-GPIO/TRD1_N: J3.17; also elsewhere on the board
/Raspberry-Pi-GPIO/TRD1_P: J3.15; also elsewhere on the board
/Raspberry-Pi-GPIO/TRD2_N: J3.9; also elsewhere on the board
/Raspberry-Pi-GPIO/TRD2_P: J3.11; also elsewhere on the board
/Raspberry-Pi-GPIO/TRD3_N: J3.5; also elsewhere on the board
/Raspberry-Pi-GPIO/TRD3_P: J3.3; also elsewhere on the board
/Raspberry-Pi-Highspeed/CAM0_C_N: J2.140 (CAM0_C_N), J4.8
/Raspberry-Pi-Highspeed/CAM0_C_P: J2.142 (CAM0_C_P), J4.9
/Raspberry-Pi-Highspeed/CAM0_D0_N: J2.128 (CAM0_D0_N), J4.2
/Raspberry-Pi-Highspeed/CAM0_D0_P: J2.130 (CAM0_D0_P), J4.3
/Raspberry-Pi-Highspeed/CAM0_D1_N: J2.134 (CAM0_D1_N), J4.5
/Raspberry-Pi-Highspeed/CAM0_D1_P: J2.136 (CAM0_D1_P), J4.6
/Raspberry-Pi-Highspeed/CAM1_C_N: J2.127 (CAM1_C_N), J5.8
/Raspberry-Pi-Highspeed/CAM1_C_P: J2.129 (CAM1_C_P), J5.9
/Raspberry-Pi-Highspeed/CAM1_D0_N: J2.115 (CAM1_D0_N), J5.2
/Raspberry-Pi-Highspeed/CAM1_D0_P: J2.117 (CAM1_D0_P), J5.3
/Raspberry-Pi-Highspeed/CAM1_D1_N: J2.121 (CAM1_D1_N), J5.5
/Raspberry-Pi-Highspeed/CAM1_D1_P: J2.123 (CAM1_D1_P), J5.6
/Raspberry-Pi-Highspeed/CAM1_D2_N: J2.133 (CAM1_D2_N), J5.11
/Raspberry-Pi-Highspeed/CAM1_D2_P: J2.135 (CAM1_D2_P), J5.12
/Raspberry-Pi-Highspeed/CAM1_D3_N: J2.139 (CAM1_D3_N), J5.14
/Raspberry-Pi-Highspeed/CAM1_D3_P: J2.141 (CAM1_D3_P), J5.15
/Raspberry-Pi-Highspeed/DSI0_C_N: J2.169 (DSI0_C_N), J6.8
/Raspberry-Pi-Highspeed/DSI0_C_P: J2.171 (DSI0_C_P), J6.9
/Raspberry-Pi-Highspeed/DSI0_D0_N: J2.157 (DSI0_D0_N), J6.2
/Raspberry-Pi-Highspeed/DSI0_D0_P: J2.159 (DSI0_D0_P), J6.3
/Raspberry-Pi-Highspeed/DSI0_D1_N: J2.163 (DSI0_D1_N), J6.5
/Raspberry-Pi-Highspeed/DSI0_D1_P: J2.165 (DSI0_D1_P), J6.6
/Raspberry-Pi-Highspeed/DSI1_C_N: J2.187 (DSI1_C_N), J7.8
/Raspberry-Pi-Highspeed/DSI1_C_P: J2.189 (DSI1_C_P), J7.9
/Raspberry-Pi-Highspeed/DSI1_D0_N: J2.175 (DSI1_D0_N), J7.2
/Raspberry-Pi-Highspeed/DSI1_D0_P: J2.177 (DSI1_D0_P), J7.3
/Raspberry-Pi-Highspeed/DSI1_D1_N: J2.181 (DSI1_D1_N), J7.5
/Raspberry-Pi-Highspeed/DSI1_D1_P: J2.183 (DSI1_D1_P), J7.6
/Raspberry-Pi-Highspeed/DSI1_D2_N: J2.193 (DSI1_D2_N), J7.11
/Raspberry-Pi-Highspeed/DSI1_D2_P: J2.195 (DSI1_D2_P), J7.12
/Raspberry-Pi-Highspeed/DSI1_D3_N: J2.194 (DSI1_D3_N), J7.14
/Raspberry-Pi-Highspeed/DSI1_D3_P: J2.196 (DSI1_D3_P), J7.15
/Raspberry-Pi-Highspeed/HDMI0_CEC: J2.151 (HDMI0_CEC), J3.57
/Raspberry-Pi-Highspeed/HDMI0_CLK_N: J2.190 (HDMI0_CLK_N), J3.72
/Raspberry-Pi-Highspeed/HDMI0_CLK_P: J2.188 (HDMI0_CLK_P), J3.70
/Raspberry-Pi-Highspeed/HDMI0_HOTPLUG: J2.153 (HDMI0_HOTPLUG), J3.51
/Raspberry-Pi-Highspeed/HDMI0_SCL: J2.200 (HDMI0_SCL), J3.55
/Raspberry-Pi-Highspeed/HDMI0_SDA: J2.199 (HDMI0_SDA), J3.53
/Raspberry-Pi-Highspeed/HDMI0_TX0_N: J2.184 (HDMI0_TX1_N), J3.66
/Raspberry-Pi-Highspeed/HDMI0_TX0_P: J2.182 (HDMI0_TX0_P), J3.64
/Raspberry-Pi-Highspeed/HDMI0_TX1_N: J2.178 (HDMI0_TX1_N), J3.60
/Raspberry-Pi-Highspeed/HDMI0_TX1_P: J2.176 (HDMI0_TX1_P), J3.58
/Raspberry-Pi-Highspeed/HDMI0_TX2_N: J2.172 (HDMI0_TX2_N), J3.54
/Raspberry-Pi-Highspeed/HDMI0_TX2_P: J2.170 (HDMI0_TX2_P), J3.52
/Raspberry-Pi-Highspeed/HDMI1_CEC: J2.149 (HDMI1_CEC), J3.33
/Raspberry-Pi-Highspeed/HDMI1_CLK_N: J2.166 (HDMI1_CLK_N), J3.48
/Raspberry-Pi-Highspeed/HDMI1_CLK_P: J2.164 (HDMI1_CLK_P), J3.46
/Raspberry-Pi-Highspeed/HDMI1_HOTPLUG: J2.143 (HDMI1_HOTPLUG), J3.27
/Raspberry-Pi-Highspeed/HDMI1_SCL: J2.147 (HDMI1_SCL), J3.31
/Raspberry-Pi-Highspeed/HDMI1_SDA: J2.145 (HDMI1_SDA), J3.29
/Raspberry-Pi-Highspeed/HDMI1_TX0_N: J2.160 (HDMI1_TX0_N), J3.42
/Raspberry-Pi-Highspeed/HDMI1_TX0_P: J2.158 (HDMI1_TX0_P), J3.40
/Raspberry-Pi-Highspeed/HDMI1_TX1_N: J2.154 (HDMI1_TX1_N), J3.36
/Raspberry-Pi-Highspeed/HDMI1_TX1_P: J2.152 (HDMI1_TX1_P), J3.34
/Raspberry-Pi-Highspeed/HDMI1_TX2_N: J2.148 (HDMI1_TX2_N), J3.30
/Raspberry-Pi-Highspeed/HDMI1_TX2_P: J2.146 (HDMI1_TX2_P), J3.28
/Raspberry-Pi-Highspeed/SCL0: J5.20, J7.20
/Raspberry-Pi-Highspeed/SCL1: J4.20, J6.20
/Raspberry-Pi-Highspeed/SDA0: J5.21, J7.21
/Raspberry-Pi-Highspeed/SDA1: J4.21, J6.21
/Raspberry-Pi-Highspeed/USB0_N: J2.103 (USB2_N); also elsewhere on the board
/Raspberry-Pi-Highspeed/USB0_P: J2.105 (USB2_P); also elsewhere on the board
/Raspberry-Pi-Highspeed/USB1_N: J3.6; also elsewhere on the board
/Raspberry-Pi-Highspeed/USB1_P: J3.4; also elsewhere on the board
GND: J2.107 (GND), J2.108 (GND), J2.113 (GND), J2.114 (GND), J2.119 (GND), J2.120 (GND), J2.125 (GND), J2.126 (GND), J2.131 (GND), J2.132 (GND), J2.137 (GND), J2.138 (GND), J2.144 (GND), J2.150 (GND), J2.155 (GND), J2.156 (GND), J2.161 (GND), J2.162 (GND), J2.167 (GND), J2.168 (GND), J2.173 (GND), J2.174 (GND), J2.179 (GND), J2.180 (GND), J2.185 (GND), J2.186 (GND), J2.191 (GND), J2.192 (GND), J2.197 (GND), J2.198 (GND), J2.MP (Mounting_Points), J3.1, J3.2, J3.7, J3.8, J3.13, J3.14, J3.19, J3.20, J3.25, J3.26, J3.32, J3.38, J3.44, J3.50, J3.56, J3.62, J3.68, J3.73, J3.74, J4.1, J4.4, J4.7, J4.10, J4.13, J4.16, J4.19, J4.MP (MountPin), J5.1, J5.4, J5.7, J5.10, J5.13, J5.16, J5.19, J5.MP (MountPin), J6.1, J6.4, J6.7, J6.10, J6.13, J6.16, J6.19, J6.MP (MountPin), J7.1, J7.4, J7.7, J7.10, J7.13, J7.16, J7.19, J7.MP (MountPin); also elsewhere on the board

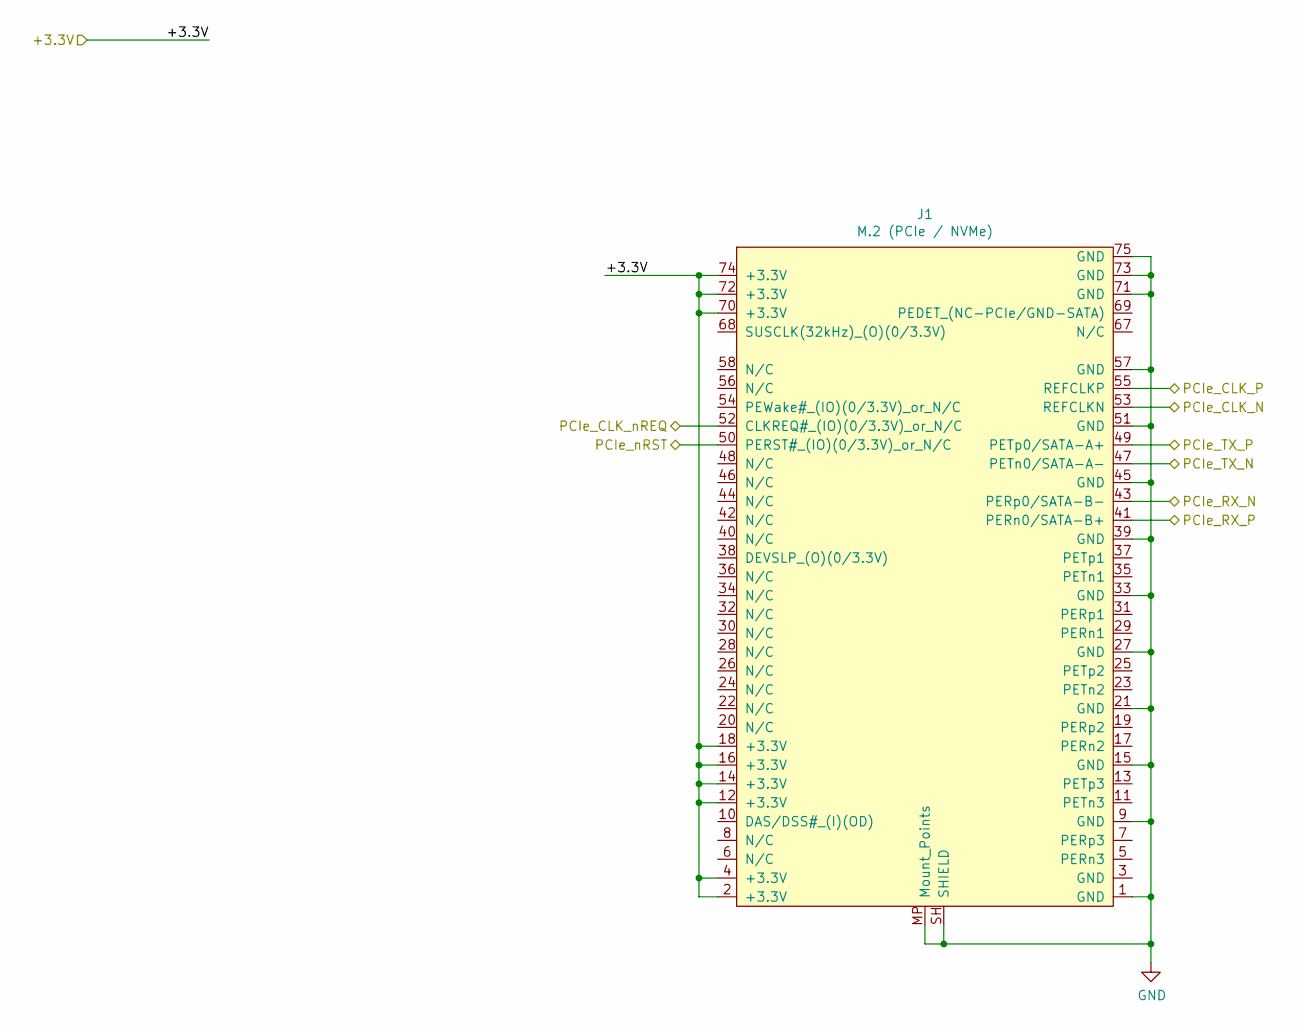
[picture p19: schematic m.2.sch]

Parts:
J1: M.2 (PCIe / NVMe); M.2_Connector

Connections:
/+3.3V: J1.2 (+3.3V), J1.4 (+3.3V), J1.12 (+3.3V), J1.14 (+3.3V), J1.16 (+3.3V), J1.18 (+3.3V), J1.70 (+3.3V), J1.72 (+3.3V), J1.74 (+3.3V); also elsewhere on the board
/M.2/PCIe_CLK_N: J1.53 (REFCLKN); also elsewhere on the board
/M.2/PCIe_CLK_P: J1.55 (REFCLKP); also elsewhere on the board
/M.2/PCIe_CLK_nREQ: J1.52 (CLKREQ#_(IO)(0/3.3V)_or_N/C); also elsewhere on the board
/M.2/PCIe_RX_N: J1.43 (PERp0/SATA-B-); also elsewhere on the board
/M.2/PCIe_RX_P: J1.41 (PERn0/SATA-B+); also elsewhere on the board
/M.2/PCIe_TX_N: J1.47 (PETn0/SATA-A-); also elsewhere on the board
/M.2/PCIe_TX_P: J1.49 (PETp0/SATA-A+); also elsewhere on the board
/M.2/PCIe_nRST: J1.50 (PERST#_(IO)(0/3.3V)_or_N/C); also elsewhere on the board
GND: J1.1 (GND), J1.9 (GND), J1.15 (GND), J1.21 (GND), J1.27 (GND), J1.33 (GND), J1.39 (GND), J1.45 (GND), J1.51 (GND), J1.57 (GND), J1.71 (GND), J1.73 (GND), J1.75 (GND), J1.MP (Mount_Points), J1.SH (SHIELD); also elsewhere on the board

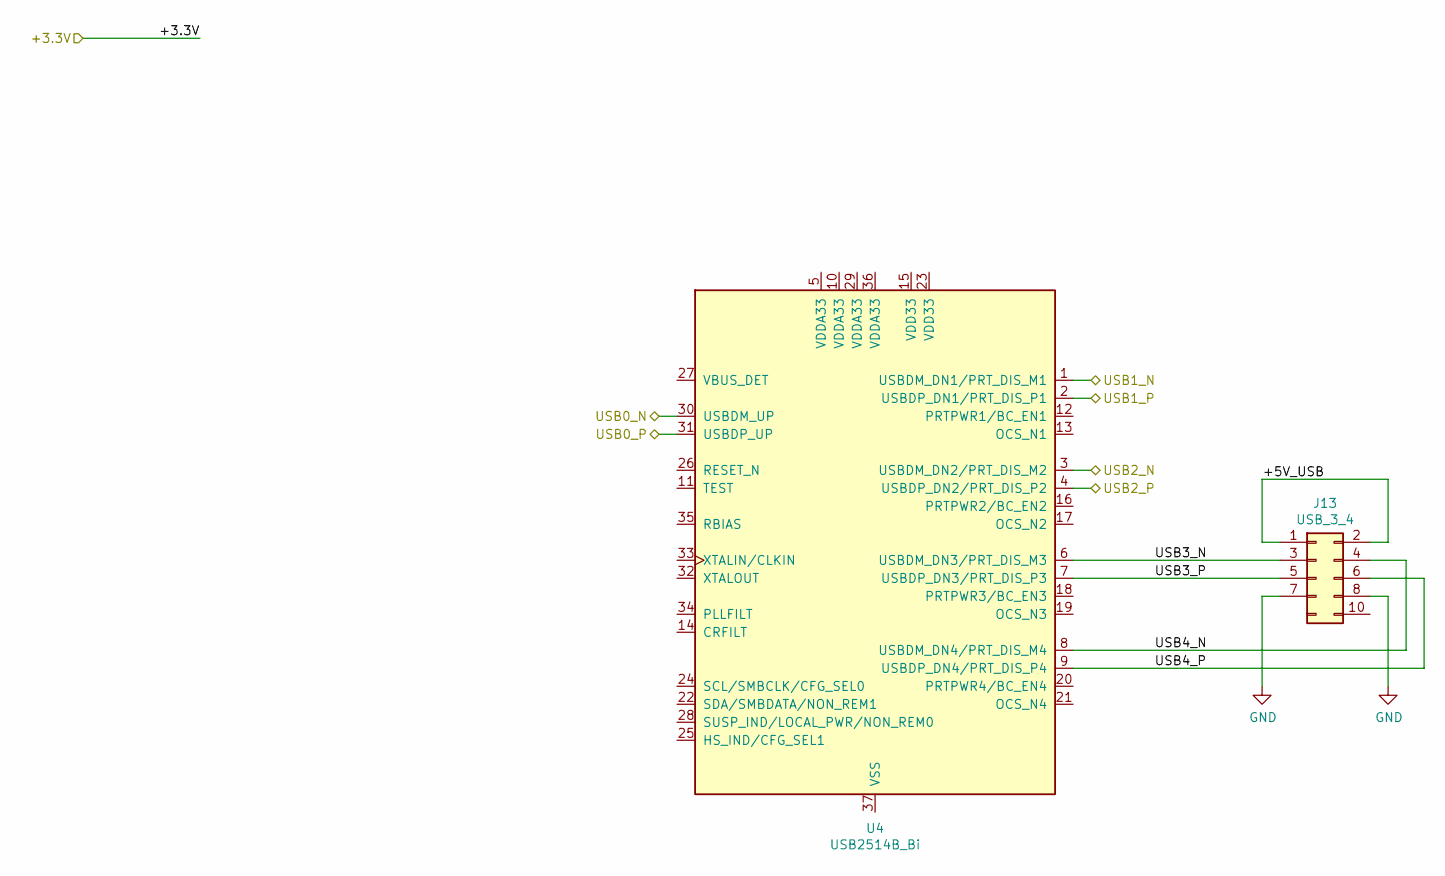
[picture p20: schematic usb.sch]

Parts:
J13: USB_3_4; PinHeader_2xUSB2_P2.54mm_Vertical_SMD
U4: USB2514B_Bi; QFN-36-1EP_6x6mm_P0.5mm_EP3.7x3.7mm

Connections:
/Raspberry-Pi-Highspeed/USB0_N: U4.30 (USBDM_UP); also elsewhere on the board
/Raspberry-Pi-Highspeed/USB0_P: U4.31 (USBDP_UP); also elsewhere on the board
/Raspberry-Pi-Highspeed/USB1_N: U4.1 (USBDM_DN1/PRT_DIS_M1); also elsewhere on the board
/Raspberry-Pi-Highspeed/USB1_P: U4.2 (USBDP_DN1/PRT_DIS_P1); also elsewhere on the board
/STM32F103/USB2_N: U4.3 (USBDM_DN2/PRT_DIS_M2); also elsewhere on the board
/STM32F103/USB2_P: U4.4 (USBDP_DN2/PRT_DIS_P2); also elsewhere on the board
/USB/+5V_USB: J13.1, J13.2
/USB/USB3_N: J13.3, U4.6 (USBDM_DN3/PRT_DIS_M3)
/USB/USB3_P: J13.5, U4.7 (USBDP_DN3/PRT_DIS_P3)
/USB/USB4_N: J13.4, U4.8 (USBDM_DN4/PRT_DIS_M4)
/USB/USB4_P: J13.6, U4.9 (USBDP_DN4/PRT_DIS_P4)
GND: J13.7, J13.8; also elsewhere on the board

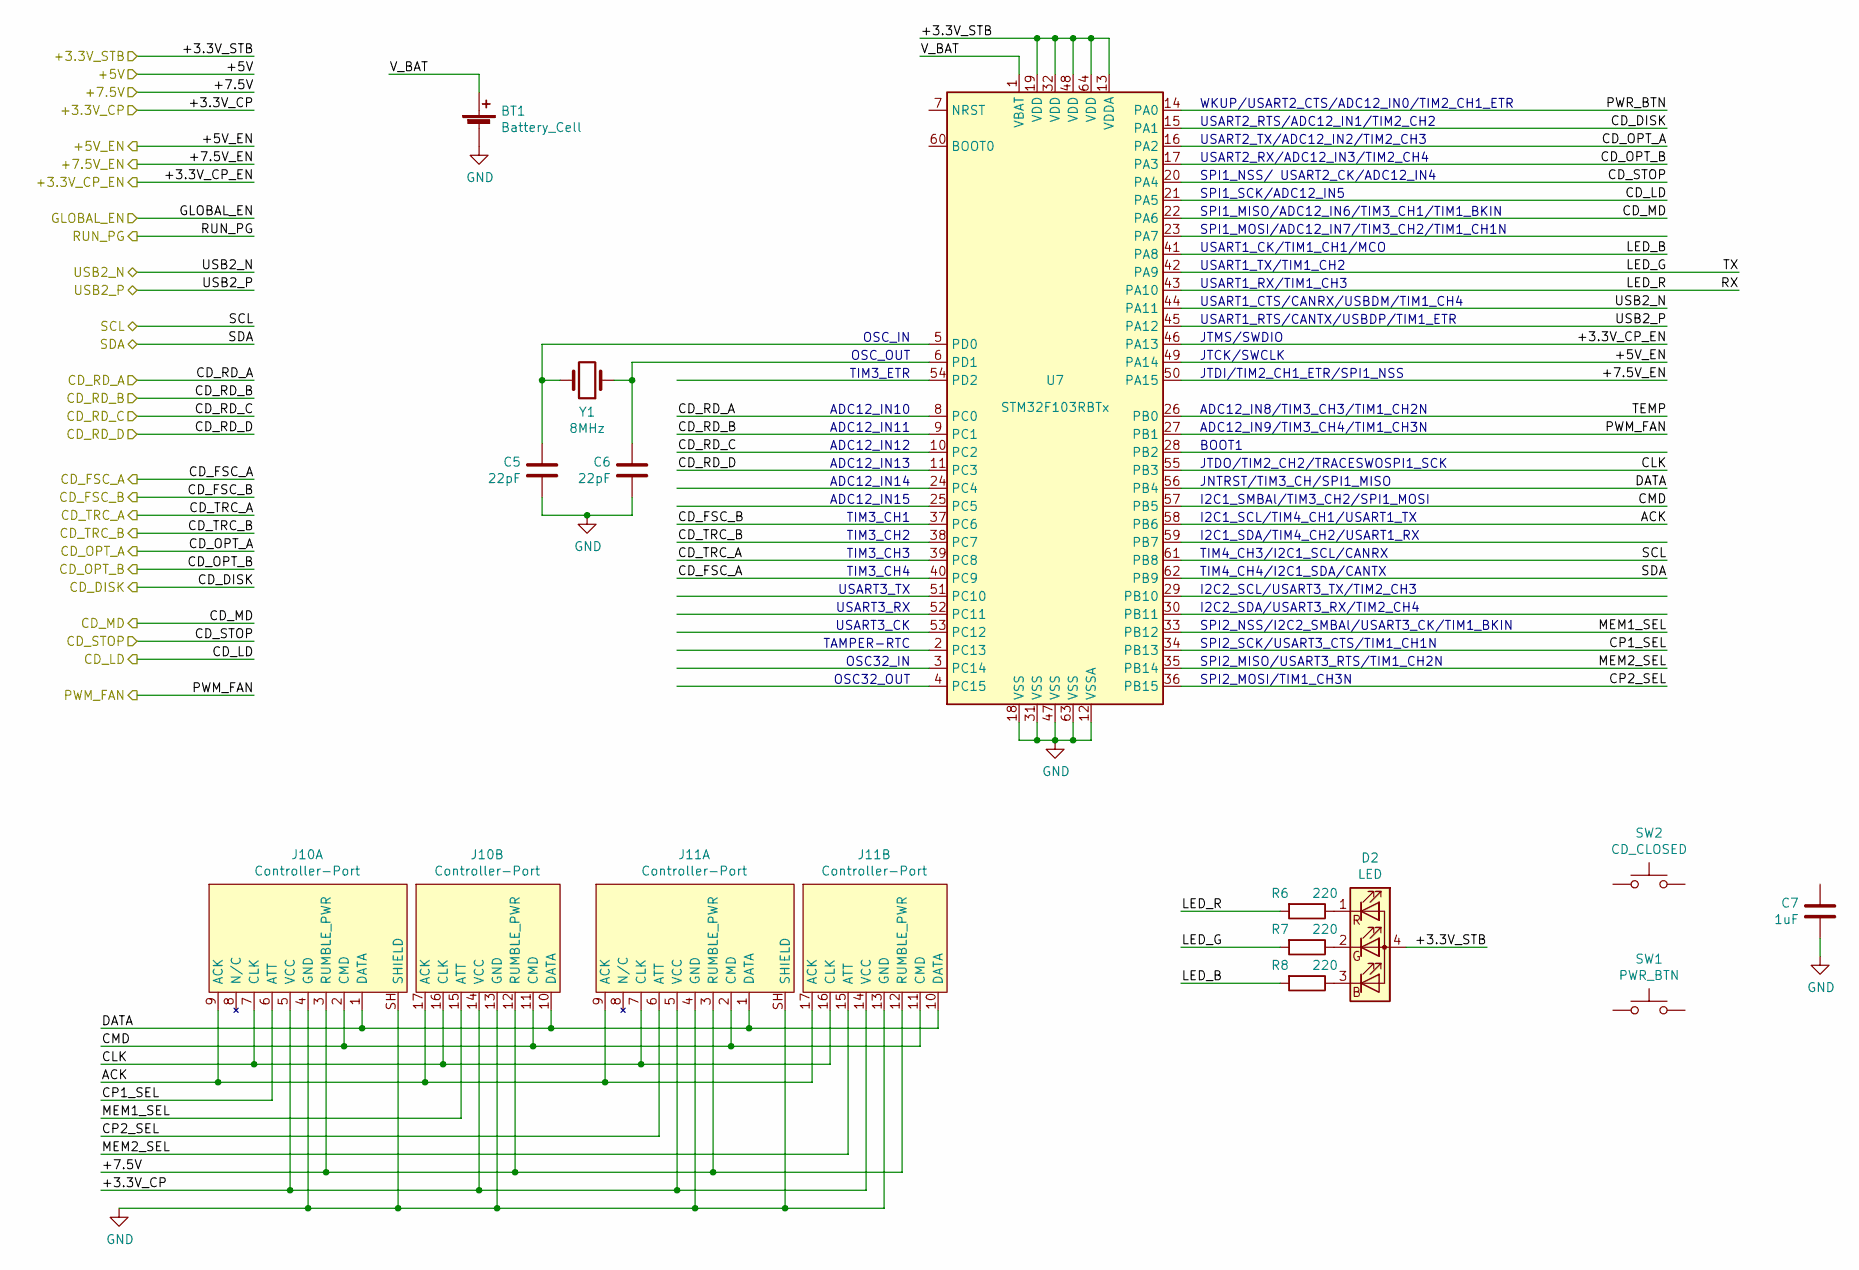
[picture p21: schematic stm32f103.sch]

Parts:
BT1: Battery_Cell; BatteryHolder_Keystone_1058_1x2032
C5, C6: 22pF; C_1206_3216Metric
C7: 1uF; C_1206_3216Metric
D2: LED; LED_RGB_1210
J10, J11: Controller-Port; PSOne-Controller-Port
R6, R7, R8: 220; R_1206_3216Metric
SW1: PWR_BTN; SW_Cherry_MX_1.00u_PCB
SW2: CD_CLOSED; SW_PUSH_6mm_H8.5mm
U7: STM32F103RBTx; LQFP-64_10x10mm_P0.5mm
Y1: 8MHz; Crystal_SMD_7050-2Pin_7.0x5.0mm

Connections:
/+3.3V_STB: D2.4 (A), U7.13 (VDDA), U7.19 (VDD), U7.32 (VDD), U7.48 (VDD), U7.64 (VDD); also elsewhere on the board
/+5V_EN: U7.49 (PA14)
/+7.5V: J10.3 (RUMBLE_PWR), J10.12 (RUMBLE_PWR), J11.3 (RUMBLE_PWR), J11.12 (RUMBLE_PWR); also elsewhere on the board
/+7.5V_EN: U7.50 (PA15)
/CD-Interface/+3.3V_CP: J10.5 (VCC), J10.14 (VCC), J11.5 (VCC), J11.14 (VCC); also elsewhere on the board
/CD-Interface/+3.3V_CP_EN: U7.46 (PA13)
/CD-Interface/CD_DISK: U7.15 (PA1); also elsewhere on the board
/CD-Interface/CD_FSC_A: U7.40 (PC9); also elsewhere on the board
/CD-Interface/CD_FSC_B: U7.37 (PC6); also elsewhere on the board
/CD-Interface/CD_LD: U7.21 (PA5); also elsewhere on the board
/CD-Interface/CD_MD: U7.22 (PA6); also elsewhere on the board
/CD-Interface/CD_OPT_A: U7.16 (PA2); also elsewhere on the board
/CD-Interface/CD_OPT_B: U7.17 (PA3); also elsewhere on the board
/CD-Interface/CD_RD_A: U7.8 (PC0); also elsewhere on the board
/CD-Interface/CD_RD_B: U7.9 (PC1); also elsewhere on the board
/CD-Interface/CD_RD_C: U7.10 (PC2); also elsewhere on the board
/CD-Interface/CD_RD_D: U7.11 (PC3); also elsewhere on the board
/CD-Interface/CD_STOP: U7.20 (PA4); also elsewhere on the board
/CD-Interface/CD_TRC_A: U7.39 (PC8); also elsewhere on the board
/CD-Interface/CD_TRC_B: U7.38 (PC7); also elsewhere on the board
/CD-Interface/PWM_FAN: U7.27 (PB1); also elsewhere on the board
/STM32F103/ACK: J10.9 (ACK), J10.17 (ACK), J11.9 (ACK), J11.17 (ACK), U7.58 (PB6)
/STM32F103/CLK: J10.7 (CLK), J10.16 (CLK), J11.7 (CLK), J11.16 (CLK), U7.55 (PB3)
/STM32F103/CMD: J10.2 (CMD), J10.11 (CMD), J11.2 (CMD), J11.11 (CMD), U7.57 (PB5)
/STM32F103/CP1_SEL: J10.6 (ATT), U7.34 (PB13)
/STM32F103/CP2_SEL: J11.6 (ATT), U7.36 (PB15)
/STM32F103/DATA: J10.1 (DATA), J10.10 (DATA), J11.1 (DATA), J11.10 (DATA), U7.56 (PB4)
/STM32F103/LED_B: R8.2, U7.41 (PA8)
/STM32F103/LED_G: R7.2, U7.42 (PA9)
/STM32F103/LED_R: R6.2, U7.43 (PA10)
/STM32F103/MEM1_SEL: J10.15 (ATT), U7.33 (PB12)
/STM32F103/MEM2_SEL: J11.15 (ATT), U7.35 (PB14)
/STM32F103/PWR_BTN: U7.14 (PA0)
/STM32F103/SCL: U7.61 (PB8); also elsewhere on the board
/STM32F103/SDA: U7.62 (PB9); also elsewhere on the board
/STM32F103/TEMP: U7.26 (PB0)
/STM32F103/USB2_N: U7.44 (PA11); also elsewhere on the board
/STM32F103/USB2_P: U7.45 (PA12); also elsewhere on the board
/STM32F103/V_BAT: BT1.1 (+), U7.1 (VBAT)
GND: BT1.2 (-), C5.1, C6.1, C7.1, J10.4 (GND), J10.13 (GND), J10.SH (SHIELD), J11.4 (GND), J11.13 (GND), J11.SH (SHIELD), U7.12 (VSSA), U7.18 (VSS), U7.31 (VSS), U7.47 (VSS), U7.63 (VSS); also elsewhere on the board
unnamed: C5.2, U7.5 (PD0), Y1.2
unnamed: C6.2, U7.6 (PD1), Y1.1
unnamed: D2.1 (RK), R6.1
unnamed: D2.2 (GK), R7.1
unnamed: D2.3 (BK), R8.1

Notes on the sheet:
OSC_IN
OSC_OUT
ADC12_IN10
ADC12_IN11
ADC12_IN12
ADC12_IN13
TAMPER-RTC
OSC32_IN
OSC32_OUT
WKUP/USART2_CTS/ADC12_IN0/TIM2_CH1_ETR
USART2_RTS/ADC12_IN1/TIM2_CH2
USART2_TX/ADC12_IN2/TIM2_CH3
USART2_RX/ADC12_IN3/TIM2_CH4
SPI1_NSS/ USART2_CK/ADC12_IN4
SPI1_SCK/ADC12_IN5
SPI1_MISO/ADC12_IN6/TIM3_CH1/TIM1_BKIN
SPI1_MOSI/ADC12_IN7/TIM3_CH2/TIM1_CH1N
ADC12_IN14
ADC12_IN15
ADC12_IN8/TIM3_CH3/TIM1_CH2N
ADC12_IN9/TIM3_CH4/TIM1_CH3N
I2C2_SDA/USART3_RX/TIM2_CH4
I2C2_SCL/USART3_TX/TIM2_CH3
SPI2_NSS/I2C2_SMBAl/USART3_CK/TIM1_BKIN
SPI2_SCK/USART3_CTS/TIM1_CH1N
SPI2_MISO/USART3_RTS/TIM1_CH2N
SPI2_MOSI/TIM1_CH3N
USART1_CK/TIM1_CH1/MCO
USART1_TX/TIM1_CH2
USART1_RX/TIM1_CH3
USART1_CTS/CANRX/USBDM/TIM1_CH4
USART1_RTS/CANTX/USBDP/TIM1_ETR
JTMS/SWDIO
JTDI/TIM2_CH1_ETR/SPI1_NSS
JTCK/SWCLK
USART3_TX
USART3_RX
USART3_CK
JTDO/TIM2_CH2/TRACESWOSPI1_SCK
JNTRST/TIM3_CH/SPI1_MISO

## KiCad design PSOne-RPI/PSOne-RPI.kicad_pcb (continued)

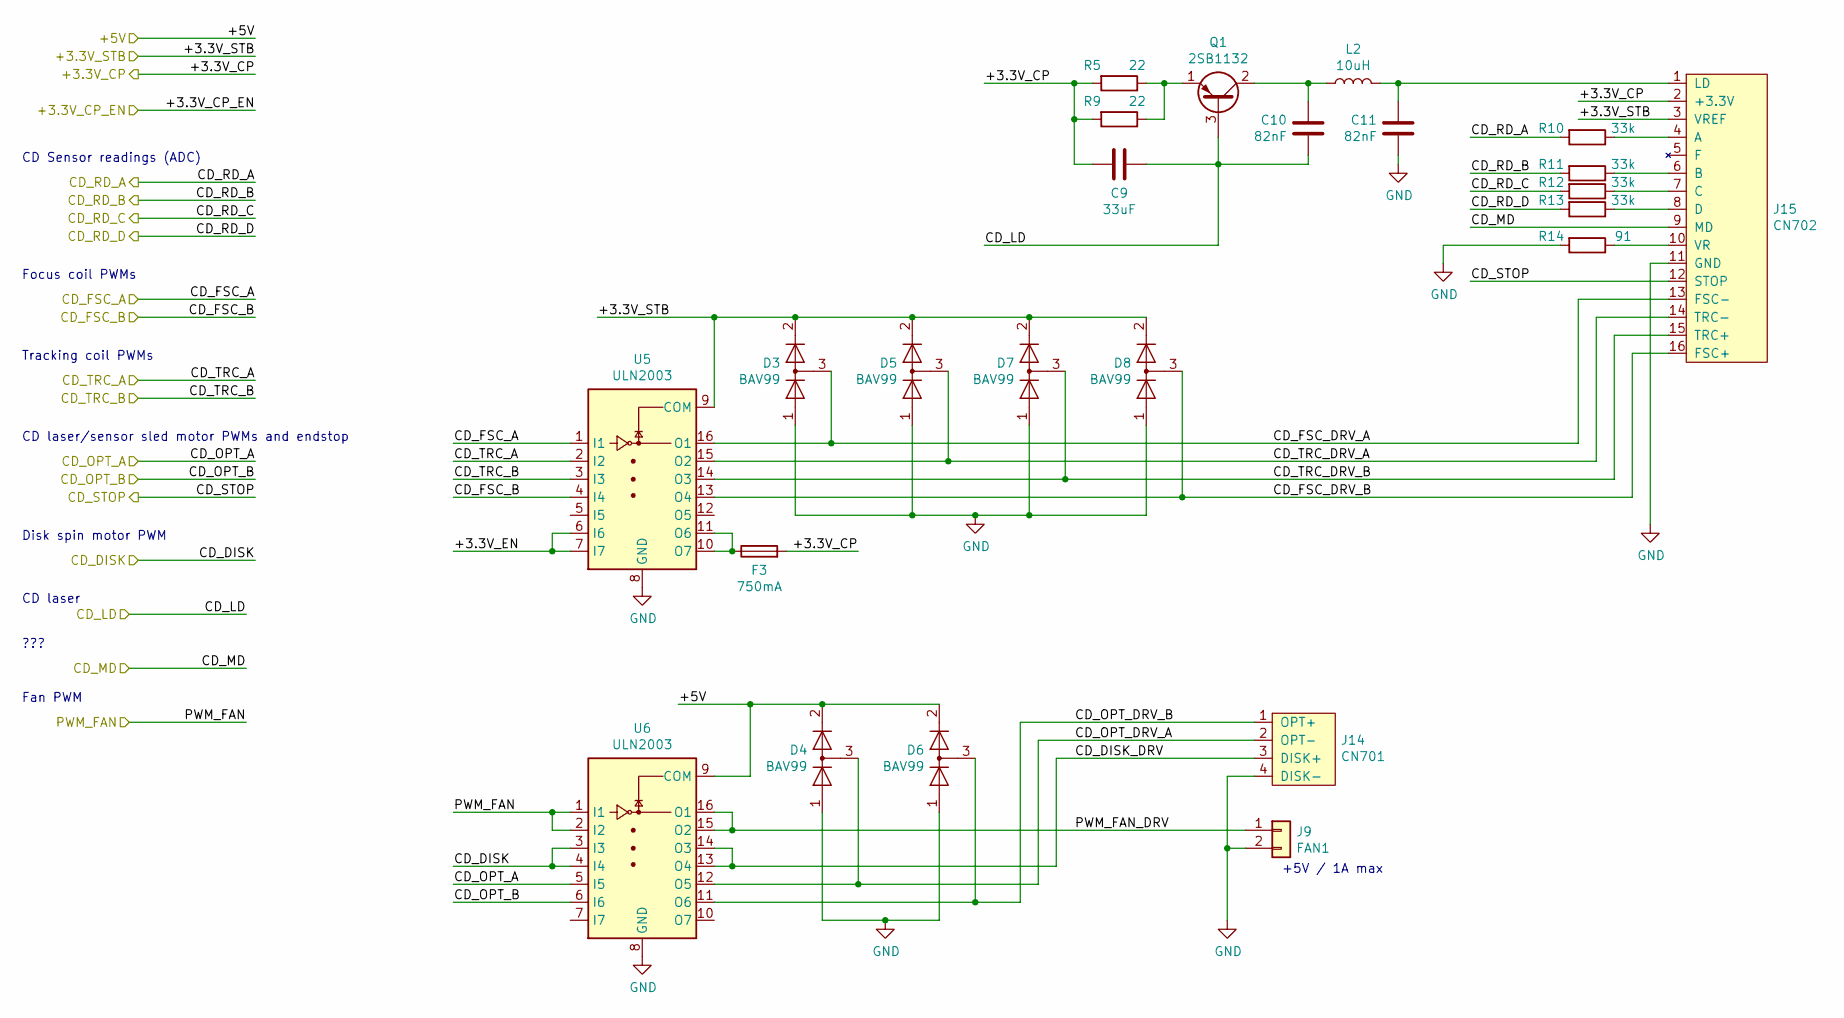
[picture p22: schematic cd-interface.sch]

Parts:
C9: 33uF; C_1206_3216Metric
C10, C11: 82nF; C_1206_3216Metric
D3, D4, D5, D6, D7, D8: BAV99; SOT-23
F3: 750mA; Fuse_1210_3225Metric
J9: FAN1; Hirose_DF13-02P-1.25DSA_1x02_P1.25mm_Vertical
J14: CN701; Hirose_DF13-04P-1.25DSA_1x04_P1.25mm_Vertical
J15: CN702; FFC-1x16-Vertical
L2: 10uH; L_1812_4532Metric
Q1: 2SB1132; SOT-23
R5, R9: 22; R_1206_3216Metric
R10, R11, R12, R13: 33k; R_1206_3216Metric
R14: 91; R_1206_3216Metric
U5, U6: ULN2003; SOIC-16_3.9x9.9mm_P1.27mm

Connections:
/+3.3V_STB: D3.2 (A), D5.2 (A), D7.2 (A), D8.2 (A), J15.3 (VREF), U5.9 (COM); also elsewhere on the board
/+5V: D4.2 (A), D6.2 (A), U6.9 (COM)
/CD-Interface/+3.3V_CP: C9.1, F3.2, J15.2 (+3.3V), R5.2, R9.2; also elsewhere on the board
/CD-Interface/+3.3V_EN: U5.6 (I6), U5.7 (I7)
/CD-Interface/CD_DISK: U6.3 (I3), U6.4 (I4); also elsewhere on the board
/CD-Interface/CD_DISK_DRV: J14.3 (DISK+), U6.13 (O4), U6.14 (O3)
/CD-Interface/CD_FSC_A: U5.1 (I1); also elsewhere on the board
/CD-Interface/CD_FSC_B: U5.4 (I4); also elsewhere on the board
/CD-Interface/CD_FSC_DRV_A: D3.3 (K), J15.13 (FSC-), U5.16 (O1)
/CD-Interface/CD_FSC_DRV_B: D8.3 (K), J15.16 (FSC+), U5.13 (O4)
/CD-Interface/CD_LD: C9.2, C10.1, Q1.3 (B); also elsewhere on the board
/CD-Interface/CD_MD: J15.9 (MD); also elsewhere on the board
/CD-Interface/CD_OPT_A: U6.5 (I5); also elsewhere on the board
/CD-Interface/CD_OPT_B: U6.6 (I6); also elsewhere on the board
/CD-Interface/CD_OPT_DRV_A: D4.3 (K), J14.2 (OPT-), U6.12 (O5)
/CD-Interface/CD_OPT_DRV_B: D6.3 (K), J14.1 (OPT+), U6.11 (O6)
/CD-Interface/CD_RD_A: R10.2; also elsewhere on the board
/CD-Interface/CD_RD_B: R11.2; also elsewhere on the board
/CD-Interface/CD_RD_C: R12.2; also elsewhere on the board
/CD-Interface/CD_RD_D: R13.2; also elsewhere on the board
/CD-Interface/CD_STOP: J15.12 (STOP); also elsewhere on the board
/CD-Interface/CD_TRC_A: U5.2 (I2); also elsewhere on the board
/CD-Interface/CD_TRC_B: U5.3 (I3); also elsewhere on the board
/CD-Interface/CD_TRC_DRV_A: D5.3 (K), J15.14 (TRC-), U5.15 (O2)
/CD-Interface/CD_TRC_DRV_B: D7.3 (K), J15.15 (TRC+), U5.14 (O3)
/CD-Interface/PWM_FAN: U6.1 (I1), U6.2 (I2); also elsewhere on the board
/CD-Interface/PWM_FAN_DRV: J9.1, U6.15 (O2), U6.16 (O1)
GND: C11.1, D3.1 (K), D4.1 (K), D5.1 (K), D6.1 (K), D7.1 (K), D8.1 (K), J9.2, J14.4 (DISK-), J15.11 (GND), R14.2, U5.8 (GND), U6.8 (GND); also elsewhere on the board
unnamed: C10.2, L2.1, Q1.2 (C)
unnamed: C11.2, J15.1 (LD), L2.2
unnamed: F3.1, U5.10 (O7), U5.11 (O6)
unnamed: J15.4 (A), R10.1
unnamed: J15.6 (B), R11.1
unnamed: J15.7 (C), R12.1
unnamed: J15.8 (D), R13.1
unnamed: J15.10 (VR), R14.1
unnamed: Q1.1 (E), R5.1, R9.1

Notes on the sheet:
+5V / 1A max
Tracking coil PWMs
Focus coil PWMs
CD Sensor readings (ADC)
CD laser/sensor sled motor PWMs and endstop
Disk spin motor PWM
CD laser
???
Fan PWM

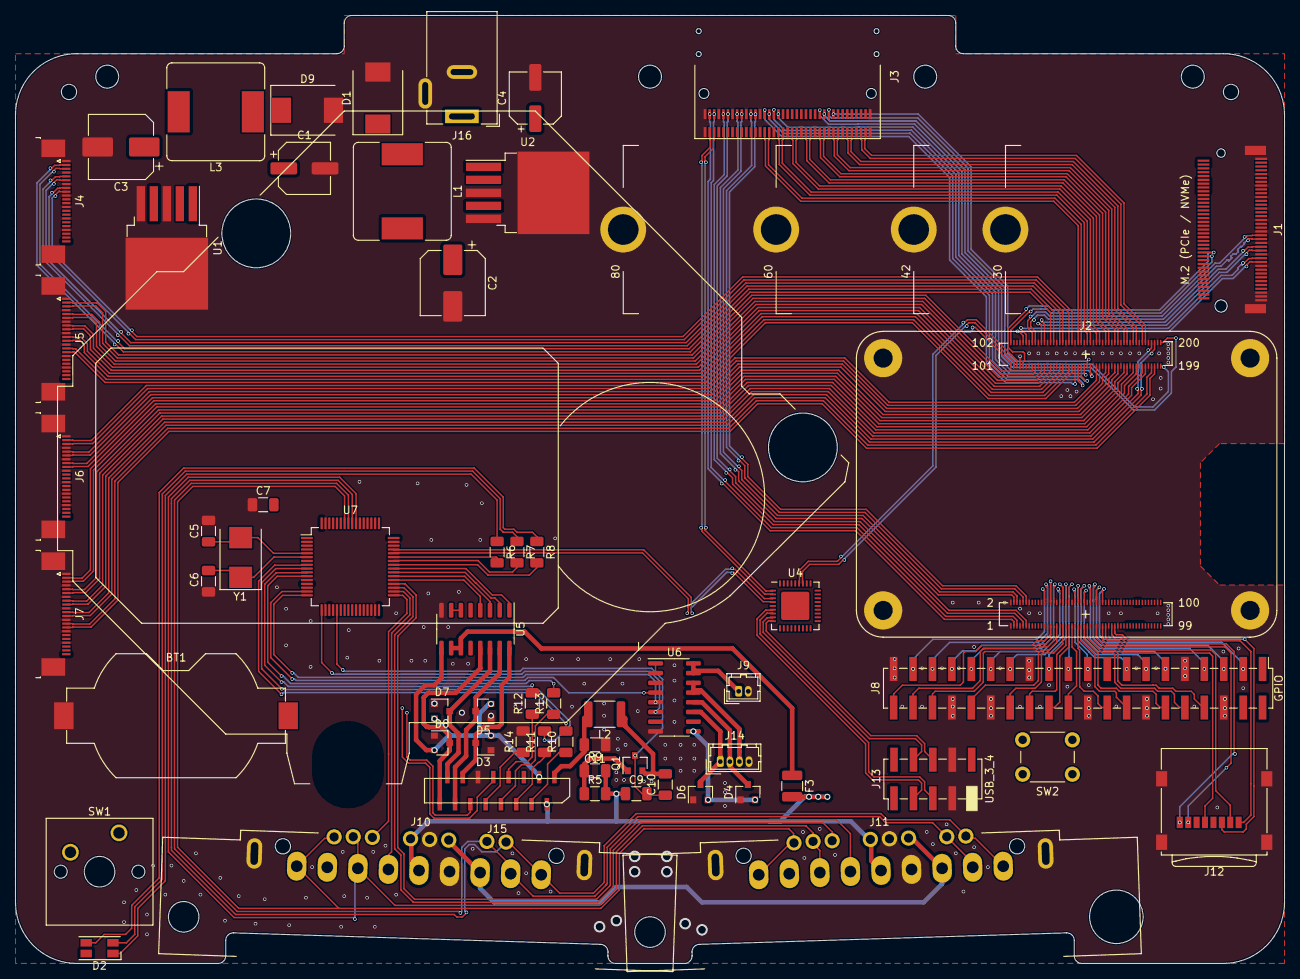
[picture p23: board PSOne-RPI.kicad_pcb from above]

Board: 2 copper layers, 166.0 x 124.0 mm, 61 parts (0 on the bottom side), 183 nets.

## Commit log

2020-12-28 Added schematic pdf
2020-12-29 Cleaned schematic and moved CD interface to extra sheet
    [PSOne-RPI.sch, m.2.sch, power-supply.sch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]
2020-12-29 Fixed naming FAN to PWM_FAN
    [stm32f103.sch]
2020-12-29 Finished CD drive interface circuit
    [PSOne-RPI.kicad_pcb, PSOne-RPI.sch, cd-interface.sch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]
2020-12-29 Updated schematic pdf
2020-12-30 Updated internal power supply
    [PSOne-RPI.kicad_pcb, estimated-power-consumption.ods, power-supply.sch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]
2021-01-01 Corrected estimated power consumption according to schematic step down conversion
    [estimated-power-consumption.ods]
2021-01-01 Added possibility to use the STM32 as RTC
    [PSOne-RPI.kicad_pcb, PSOne-RPI.sch, power-supply.sch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]
